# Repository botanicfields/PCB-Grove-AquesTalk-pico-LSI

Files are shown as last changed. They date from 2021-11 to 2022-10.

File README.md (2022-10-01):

# PCB-Grove-AquesTalk-pico-LSI
# AquesTalk pico LSI用Grove(M5)接続基板
AquesTalk pico LSI into the Grove of M5

# 1. 概要
　「AquesTalk pico LSI用Grove(M5)接続基板」は、市販の音声合成専用LSI「AquesTalk pico LSI」（別売）をGroveコネクタでM5シリーズに接続するための基板です。  
　AquesTalk pico LSIの詳細は、データシートを参照ください。
- [Data Sheet: 音声合成 LSI 「AquesTalk pico LSI」ATP3011](https://www.a-quest.com/archive/manual/atp3011_datasheet.pdf)
- [Data Sheet: 音声合成 LSI 「AquesTalk pico LSI」ATP3012](https://www.a-quest.com/archive/manual/atp3012_datasheet.pdf)

### 基板V03 の変更点
　2022年10月から基板V03を提供しています。ピンソケットJ7を追加しました。

### 委託販売
（スイッチサイエンス扱い）[AquesTalk pico LSI用Grove(M5)接続基板](https://www.switch-science.com/catalog/7625/)

### 動作例
- (YouTube）[AquesTalk pico LSI into the Grove of M5](https://youtu.be/mju6NteZsHU)  
M5AtomにI2Cで接続しています。以下のサンプルプログラムを使用しています。  
[GitHub: botanicfields/PCB-Grove-AquesTalk-pico-LSI/tree/main/BF-035_Wire](https://github.com/botanicfields/PCB-Grove-AquesTalk-pico-LSI/tree/main/BF-035_Wire)
- (YouTube）[般若心経 by AquesTalk pico LSI and M5Stack, Glove PCB, I2C](https://youtu.be/BDH4y0ca8p8)  
M5SrackにI2Cで接続しています。基板V03のJ7とM5StackのGPIO35をジャンパワイヤーで接続しています。以下のサンプルプログラムを使用しています。  
[GitHub: botanicfields/PCB-MBUS-AquesTalk-pico-LSI/tree/main/BF-034_han-nya](https://github.com/botanicfields/PCB-MBUS-AquesTalk-pico-LSI/tree/main/BF-034_han-nya)

### 組み立て例
　AquesTalk piso LSI（28ピンDIPタイプ）1個をICソケットに装着します。ATP3011用とATP3012用のソケットがあります。どちらか一方のみを装着してください。  
AquestTalk pico LSIの取り付け: 左 ATP3011, 右 ATP3012  
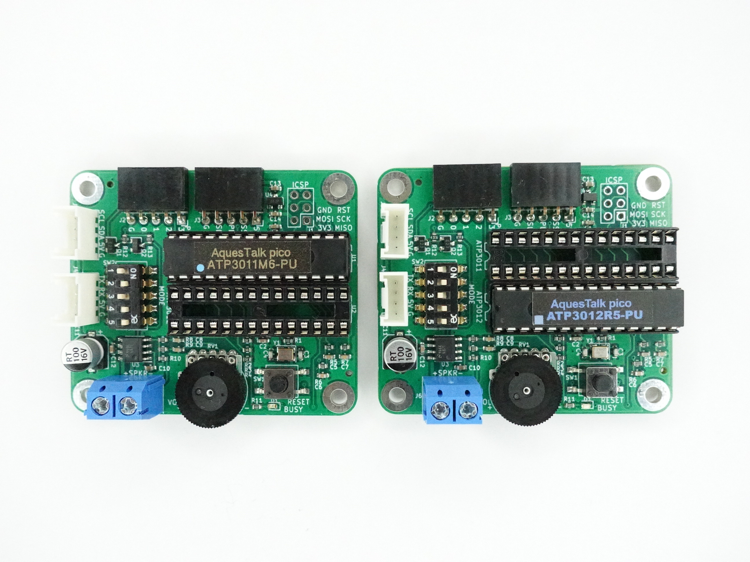
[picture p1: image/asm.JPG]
  

## 1.1 特徴
- AquesTalk pico LSI（28ピンDIPタイプ）1個を搭載できます。
- ATP3011, ATP3012の両方に対応しています。
- パワーアンプ（LM4871）を内蔵し、スピーカーを直接駆動できます。
- M5シリーズのGrove仕様に合わせ、電源+5V、信号3.3Vに対応します。
- AquestTalk pico LSIは3.3Vで動作し、M5シリーズに直結できます。
- DIPスイッチで動作モード・通信モードを設定できます。
- 動作モード・通信モードの変更を反映するリセットボタンがあります。
- I2C接続用、UART接続用のGroveコネクタがあり、接続方法を選べます。
- スタンドアロンモードのためのコネクタがあります。
- SPI接続も可能です（ハンダ付けが必要です）。

DIP: Dual In-line Package  
I2C: Inte-Integrated Circuit  
UART: Universal Asynchronous Receiver Transmitter  
SPI: Serial Peripheral Interface

## 1.2 内容物
- AquesTalk pico LSI用Grove(M5)接続基板（完成品）1枚  
- Groveケーブル20cm 1本（M5Stack純正品）  
- 説明書 1部  

※ AquesTalk pico LSIは付属しません。  
※ スピーカー、スピーカーケーブルは付属しません。  
※ ケースや足などは付属しません。

### 商品写真（基板V03）
写真: 内容物、基板裏面  
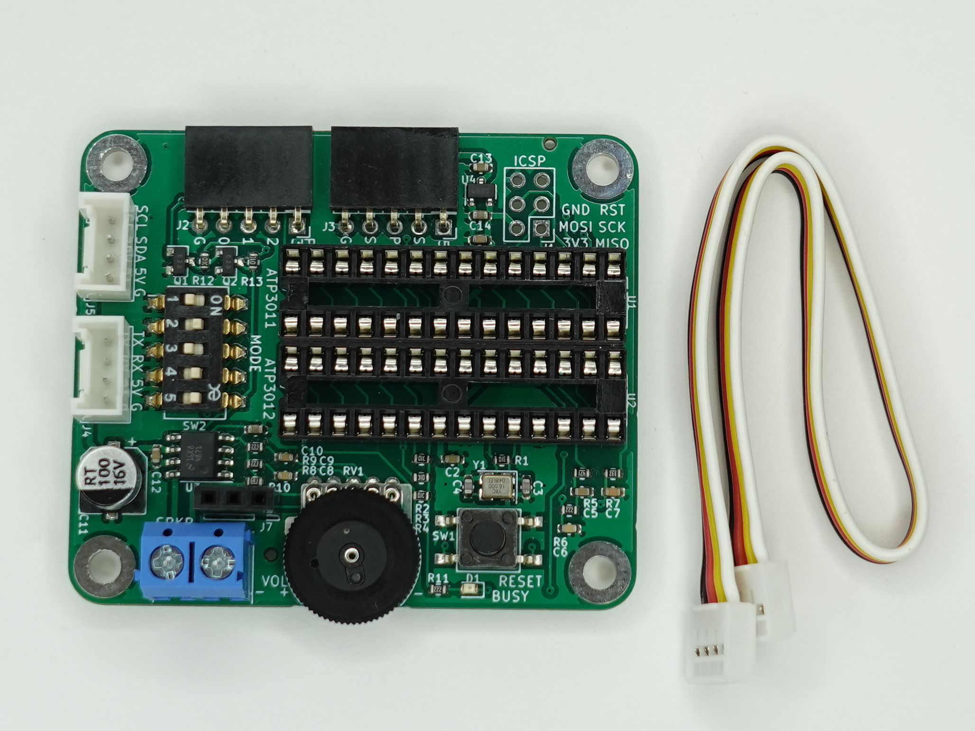
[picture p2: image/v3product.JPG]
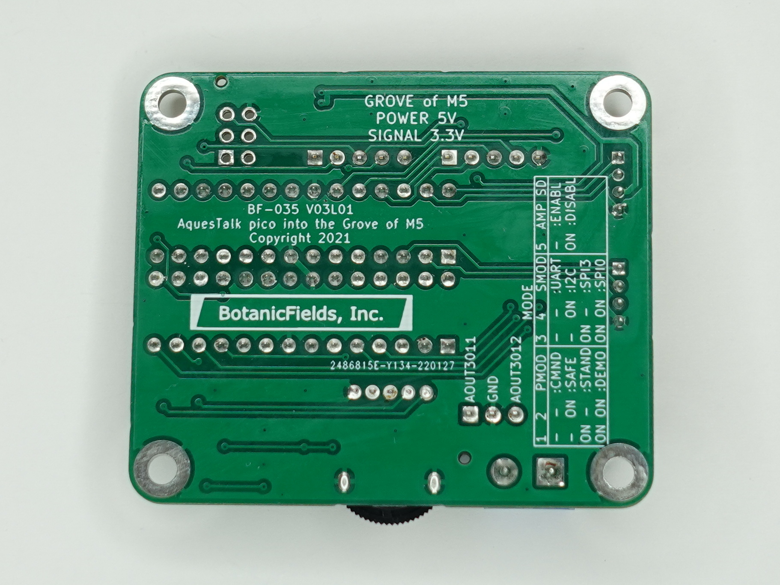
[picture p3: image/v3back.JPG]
   

## 1.3 別途必要なもの
- AquesTalk pico LSI（秋月電子通商扱い）  
[音声合成ＬＳＩ　ＡＴＰ３０１１Ｆ１－ＰＵ（ゆっくりな女性の音声）
ATP3011F1-PU](https://akizukidenshi.com/catalog/g/gI-06220/)  
[音声合成ＬＳＩ　ＡＴＰ３０１１Ｆ４－ＰＵ（かわいい女性の音声）
ATP3011F4-PU](https://akizukidenshi.com/catalog/g/gI-05665/)  
[音声合成ＬＳＩ　ＡＴＰ３０１１Ｍ６－ＰＵ（男性の音声）
ATP3011M6-PU](https://akizukidenshi.com/catalog/g/gI-06225/)  
[音声合成ＬＳＩ　ＡＴＰ３０１２Ｆ６－ＰＵ（女性の音声明瞭版）
ATP3012F6-PU](https://akizukidenshi.com/catalog/g/gI-09973/)  
[音声合成ＬＳＩ　ＡＴＰ３０１２Ｒ５－ＰＵ（小型ロボットの音声）
ATP3012R5-PU](https://akizukidenshi.com/catalog/g/gI-11517/)  
- スピーカー、スピーカーケーブル  
4～8Ω程度、1W以上が望ましいです
- 工具  
ドライバ（ターミナルブロックの締め付けに必要です）など
- M5Stack, M5Atom  
サンプルプログラムは、M5Stack Core Basic, M5Atomで動作を確認しています
- Arduino-IDEが動作する環境  
サンプルプログラムは、Arduino IDE用です
- その他  
SLEEP信号などを接続する場合には、ジャンパワイヤー等が必要です。SPI接続の場合には、ピンヘッダおよびハンダ付けが必要です

# 2. 接続

## 2.1 I2C接続
　SCL, SDAの表記のあるGroveコネクタJ5に接続します。基板上にプルアップ抵抗はありません。M5シリーズ側でのプルアップを使用します。

### (1)M5AtomのGroveコネクタに接続  
　I2Cとして、SCL=GPIO32, SDA=GPIO26を指定します。サンプルプログラムではWire1を選択します。

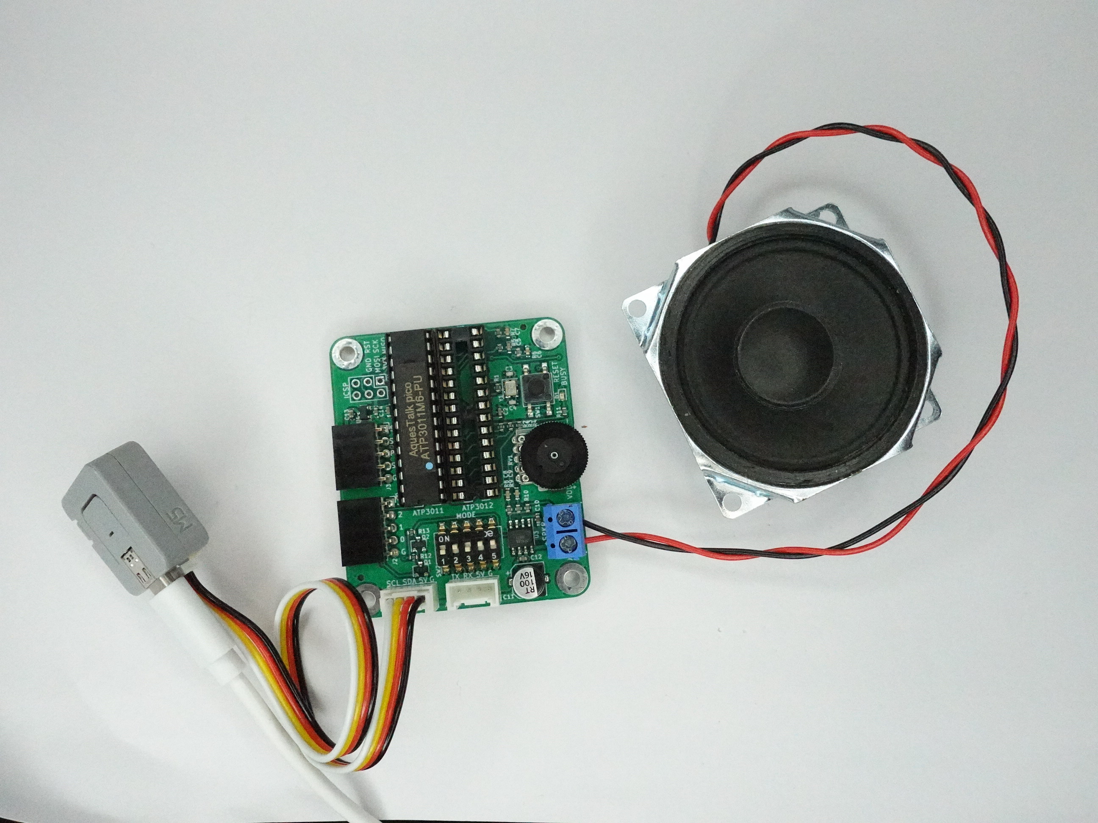
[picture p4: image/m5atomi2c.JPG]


### (2)「M5Atom用GROVEコネクタ基板※（別売）」経由で接続  
　I2Cとして、デフォルトのWire（SCL=GPIO21, SDA=GPIO25）を使用できます。  
※（スイッチサイエンス扱い）[M5Atom用GROVEコネクタ基板](https://www.switch-science.com/catalog/7309/)

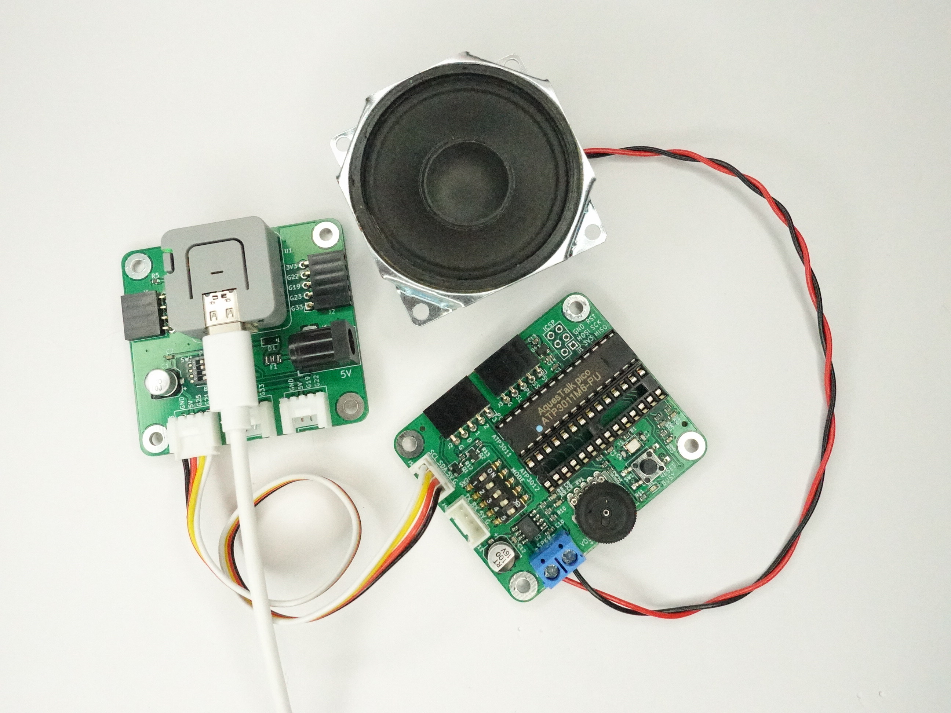
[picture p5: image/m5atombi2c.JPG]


### (3)M5StackのGroveコネクタに接続  
　I2Cとして、デフォルトのWire（SCL=GPIO22, SDA=GPIO21）を使用できます。

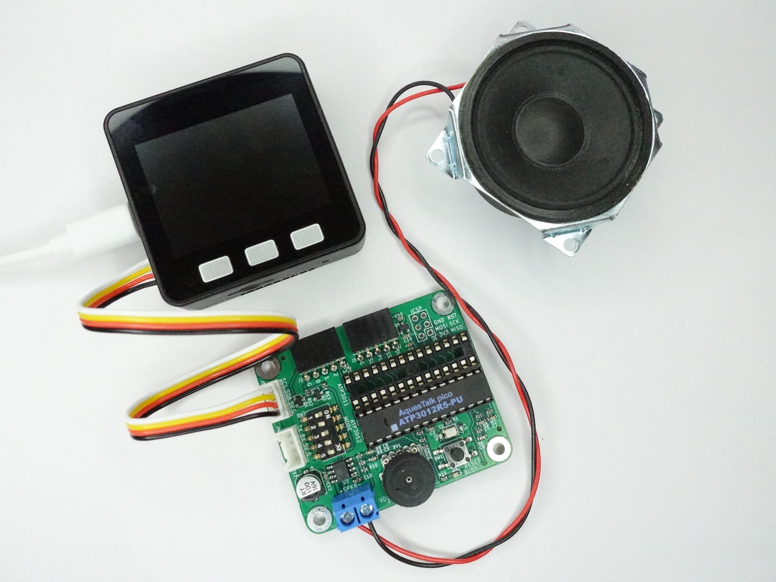
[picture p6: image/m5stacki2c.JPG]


## 2.2 UART接続
　TX, RXの表記のあるGroveコネクタJ4に接続します。基板上のTXがM5シリーズのRXに、基板上のRXがM5シリーズのTXに接続されます。

### (1)M5AtomのGroveコネクタに接続  
　M5Atom側は、RX=GPIO32, TX=GPIO26を指定します。

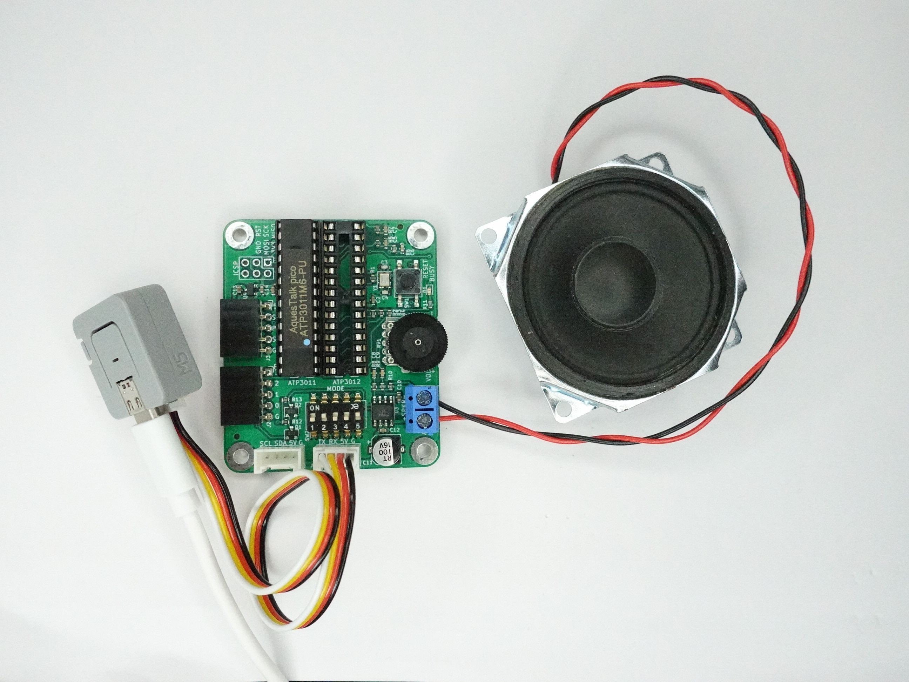
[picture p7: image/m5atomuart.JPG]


### (2)M5StackのGPIOに接続  
　接続には、「GROVE - 4ピン - ジャンパオスケーブル※（別売）」相当のケーブルが必要です。M5Stack側は、RX=GPIO16, TX=GPIO17, +5V, GND を接続します。  
※（スイッチサイエンス扱い）[GROVE - 4ピン - ジャンパオスケーブル](https://www.switch-science.com/catalog/6245/)

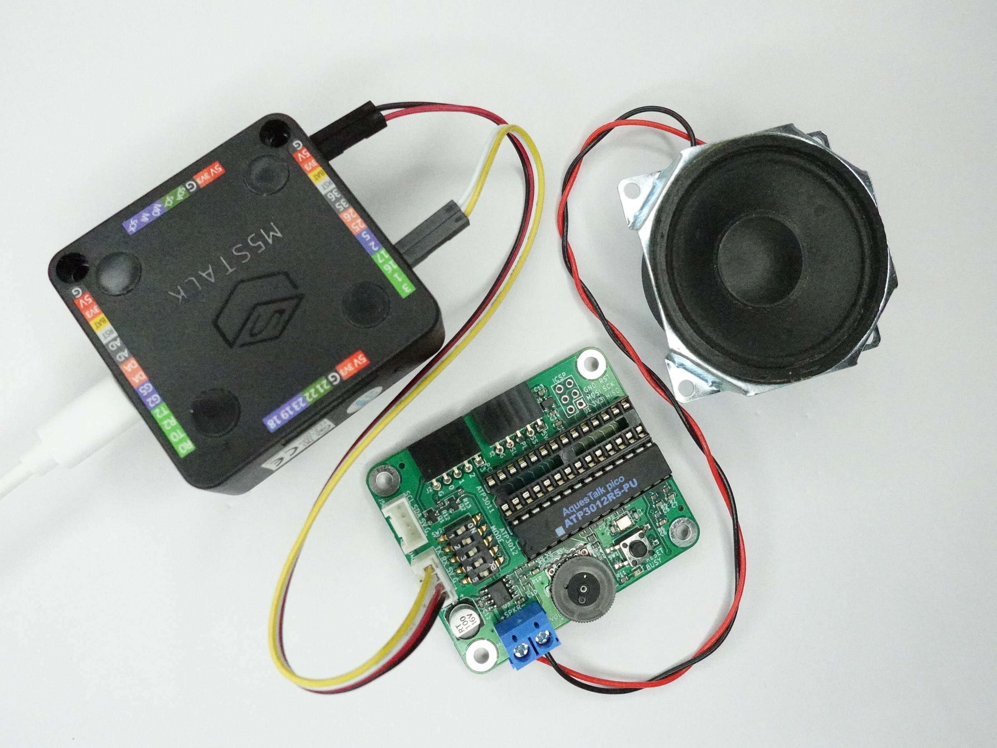
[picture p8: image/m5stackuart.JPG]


## 2.3 SPI接続
　SS, +5V, GNDは、ピンソケットJ3に接続します。SCK, MOSI, MISOは、J1(ICSP)に接続します。ICSPのピンヘッダは実装していません。ピンヘッダを別途手配いただき、基板へハンダ付けしてください。接続にはジャンパワイヤー等が必要です。
- SPI: Serial Periphral Interface
- SCK: Serial ClocK
- MOSI: Master Out Slave In
- MISO: Master In Slave Out
- SS: Slave Select
- GND: Ground
- ICSP: In Circuit Serial Programming

### M5StackのGPIOに接続
　接続にはジャンパワイヤー等が必要です。SCK=GPIO18, MISO=GPIO19, MOSI=GPIO23, SS=GPIO5, +5V, GND を接続します。

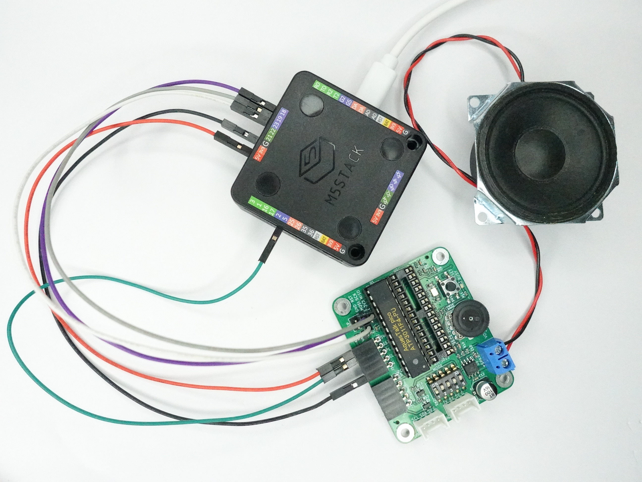
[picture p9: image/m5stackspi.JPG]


## 2.4 スタンドアロン
　J2に「ダイオードマトリクススイッチ16基板※」を接続し、ボタン操作で15種類の音声を再生できます。以下の写真でM5Stackは、電源として使用しています。  
※（スイッチサイエンス扱い）[ダイオードマトリクススイッチ16基板](https://www.switch-science.com/catalog/7626/)

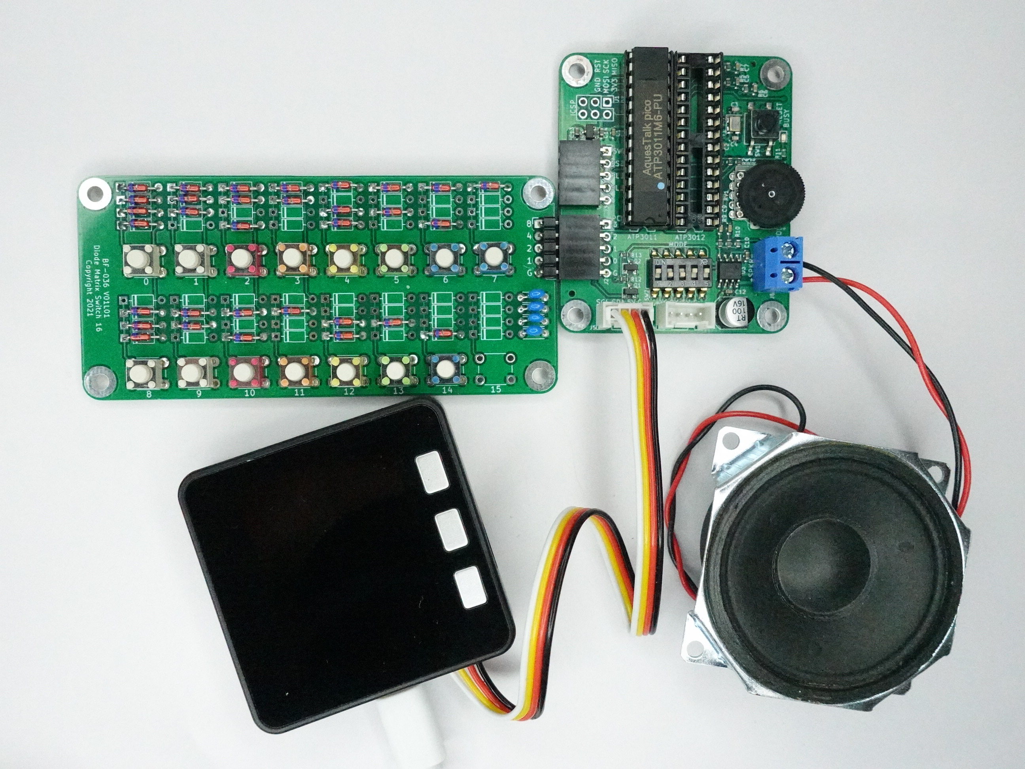
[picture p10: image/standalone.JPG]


## 2.5 その他共通
### J3 SLEEP信号
　AquesTalk pico LSIのSLEEPピンをGPIOに接続できます。SLEEP=LowでAquesTalk pico LSIがスリープ状態になります。ATP3011のUART接続において9600bpsより速い速度が必要な場合、「セーフモード」ではなく「コマンド入力モード」が必要であり、速度設定のためにSLEEPの接続が必要です。

### J3 PLAY信号
　AquesTalk pico LSIのPLAYピンをGPIOに接続できます。AquesTalk pico LSIが音声再生中の間、PLAY=Lowとなります。

### J6 スピーカー
　スピーカーを接続します。2本のいずれもGNDではありません。

### J7 音声信号（基板V03）
　音量調節ボリュームに入る時点のアナログ音声をジャンパワイヤー等に取り出すことができます。ATP3011、ATP3012でピンが異なります。  
ATP3011の例  
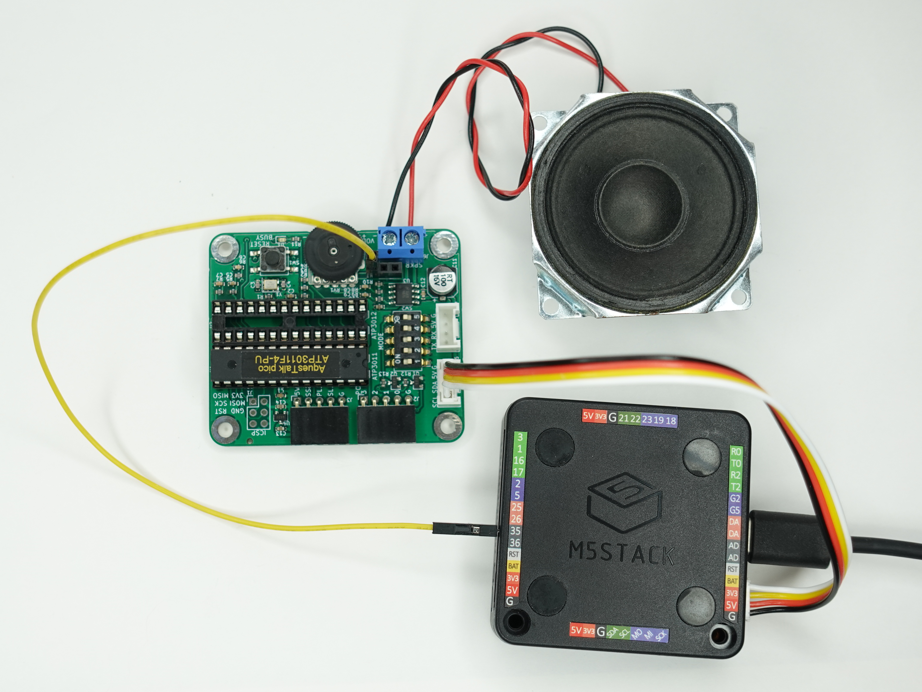
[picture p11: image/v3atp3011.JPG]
  
ATP3012の例  
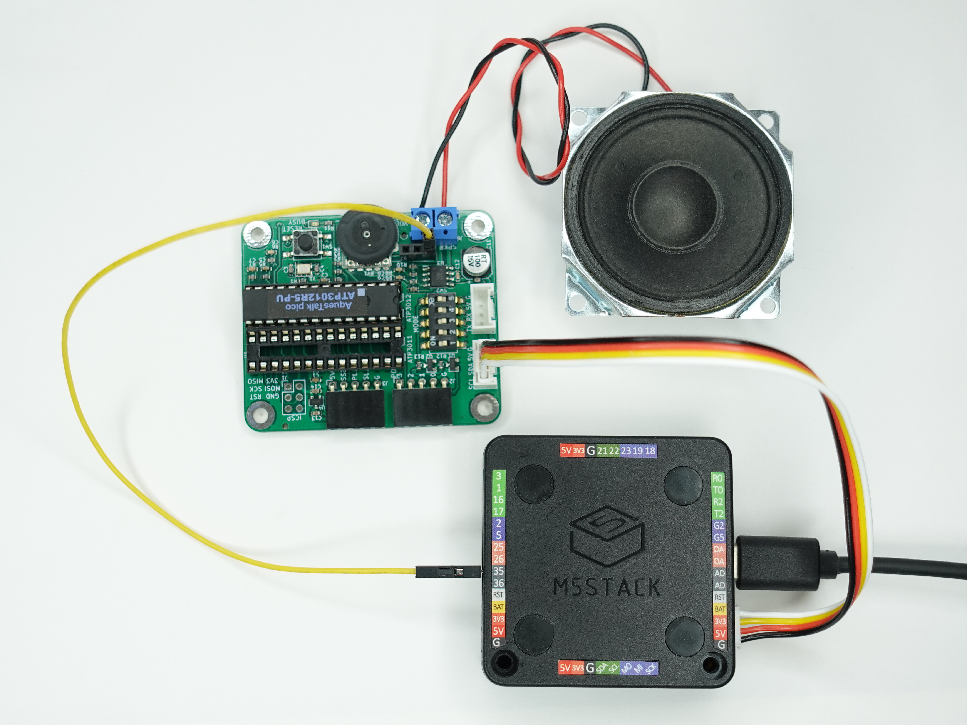
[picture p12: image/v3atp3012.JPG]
  

# 3. 設定（DIPスイッチ）
　動作モードおよび使用するインタフェース（通信モード）に合わせて、基板上のDIPスイッチを設定します。おすすめはI2C接続です。DIPスイッチの設定はリセット時に反映されます。**DIPスイッチの設定を変更後、基板上のリセットボタンを押す必要があります**。出荷時の設定は、セーフモード・I2C接続・パワーアンプが常に動作状態（OFF,ON,OFF,ON,ON）です。

| 1 | 2 | 3 | 4 | 5 |動作モード|通信モード|備考|
|:-:|:-:|:-:|:-:|:-:|:-:|:-:|:- |
|OFF|OFF|OFF|ON | - | コマンド入力モード |I2C |I2CアドレスはEEPROMに設定した値（初期値0x2E）|
|OFF|ON |OFF|ON | - | セーフモード |I2C |I2Cアドレスは強制的に0x2E|
|OFF|OFF|OFF|OFF| - | コマンド入力モード |UART|設定されたスピードで動作 (*1) |
|OFF|ON |OFF|OFF| - | セーフモード |UART|強制的に9600bpsで動作|
|OFF| - |ON |OFF| - | - | SPI mode 3 | - |
|OFF| - |ON |ON | - | - | SPI mode 0 |サンプルプログラムはSPI mode 0で動作|
|ON |OFF| - | - | - | スタンドアロンモード | - |PC0-3の信号入力によりプリセットメッセージを選択して再生|
|ON |ON | - | - | - | デモモード | - |プリセットメッセージを順番に自動再生|
| - | - | - | - |ON | - | - |パワーアンプが常に動作状態 |
| - | - | - | - |OFF| - | - |音声再生中以外は、パワーアンプをシャットダウンする(*2)|

※ 1, 2, 3, 4, 5は、DIPスイッチの番号です。DIPスイッチはONでGND接続のため、ON=0, OFF=1です。  
(*1) ATP3011の場合、SLEEP解除後の'?'送信で自動設定します。ATP3012の場合EEPROMに設定します。  
(*2) 音声再生の前後にノイズが発生します。

# 4. サンプルプログラム
　AquesTalk pico LSIをM5StackまたはM5Atomに接続し、I2C(Wire), UART(Serial), SPIで動作させるプログラムです。デモの内容は同じです。Arduino-IDE環境で使用します。基板の接続や設定を予め使用するインタフェースに合わせておく必要があります。

### BF-035_Wireフォルダ
　AqeusTalk pico LSIをI2Cで動作させるサンプルプログラムです。#defineでM5Stack, M5Atomのいずれかを選択します。

### BF-035_Serialフォルダ
　AqeusTalk pico LSIをUARTで動作させるサンプルプログラムです。#defineでM5Stack, M5Atomのいずれかを選択します。

### BF-035_Spiフォルダ
　AqeusTalk pico LSIを SPIで動作させるサンプルプログラムです。M5Stack専用です。

## 4.1 ボタン操作 .. loop()
　ボタンを押すと、ソースコードのpreset_msgを発声します。初期値はpreset_msg[0]です。

| M5 | ボタン | 停止中 | 発声中 |
|:-:|:-:|:-:|:-:|
|M5Stack| A | 1つ前のpreset_msgを発声 | 発声を中断して1つ前のpreset_msgを発声 |
|M5Stack| B | 現在のpreset_msgを発声 | 発声を中断して停止 |
|M5Stack| C | 1つ後のpreset_msgから連続して発声 | 発声を中断して1つ後のpreset_msgから連続して発生 |
|M5Atom | Btn | 現在のpreset_msgから連続して発声 | 発声を中断して停止 |

## 4.2 setup()
- SLEEPピンをHighにする（デフォルト: 実行しない）  
　AquesTalk pico LSIのSLEEPピンとが接続したGPIO5をHIGHにしてSLEEPでない状態にします。

- UARTスピードを設定（ATP3011が対象。UARTのみ。デフォルト: 実行しない）  
　AquesTalk pico LSI (ATP3011) のUARTスピードを設定します。GPIO5がAquesTalk pico LSIのSLEEPピンと接続している必要があります。

- UARTスピードを書き換え（ATP3012が対象。UARTのみ。デフォルト: 実行しない）  
　AquesTalk pico LSI (ATP3012) のUARTスピードを書き換えます。

- I2Cアドレスを書き換え（I2Cのみ。デフォルト: 実行しない）  
　AquesTalk pico LSIのI2Cアドレスを書き換えます。

- プリセットメッセージを書き込む（デフォルト: 実行しない）  
　AquesTalk pico LSIにプリセットメッセージとして、ソースコード内のpreset_msgデータを書き込みます。時間がかかります。

- EEPROMデータをダンプ（デフォルト: 実行しない）  
　AquesTalk pico LSIのEEPROMデータをシリアルモニタに表示します。時間がかかります。

- AquesTalk pico LSIのバージョンをシリアルモニタに表示

- チャイムJを発声

- チャイムKを発声

# 5. ライブラリ
　AquesTalk pico LSIを使用するためのライブラリです。

## 5.1 BF_AquesTalkPico.h
　I2C, UART, SPI共通の基本クラスです。接続するインタフェースに依ってI2C(Wire), UART(Serial), SPIのいずれかの派生クラスを使用する必要があります。

### (1) virtual int Send(const char* msg) = 0
　AquesTalk pico LSIに文字列msgを送信します。送信の様子をシリアルモニタに出力します。純粋仮想関数として定義し、使用するインタフェースに合わせて派生クラスで実装します。

### (2) virtual size_t Recv(char* res, size_t res_size) = 0
　AquesTalk pico LSIから文字列を受信します。受信完了は、'>'または'*'で判断します。純粋仮想関数として定義し、使用するインタフェースに合わせて派生クラスで実装します。

### (3) virtual bool Busy() = 0
　発声中などAquesTalk pico LSIが処理中の場合trueを応答します。falseの場合発声が終了したと判断できます。純粋仮想関数として定義し、使用するインタフェースに合わせて派生クラスで実装します。I2C, SPIではおのずとポーリングができますが、UARTではSend()による明示的なポーリングが必要です。

### (4) int ShowRes(int res_length_to_show = 1)
　AquesTalk pico LSIからの応答をシリアルモニタに出力します。res_length_to_showに2を渡すと、応答が1文字以下の場合にシリアルモニタへの出力を抑止できます。I2C、SPIのポーリングによる応答が正常（'>', 1文字）の場合のシリアルモニタへの出力を省略できます。

### (5) int DumpEeprom()
　AquesTalk pico LSIのEEPROM (アドレス0x000-0x3FF) の値をシリアルモニタに出力します。

### (6) int WriteEeprom(int address, int data)
　AquesTalk pico LSIのEEPROMにデータを書き込みます。

### (7) int WritePresetMsg(const char* msg[], int num_of_msg)
　AquesTalk pico LSIのEEPROMにプリセットメッセージを書き込みます。書き込みの様子をシリアルモニタに出力します。

### (8)  int WriteSpeed(int speed)
　発話速度をEEPROMに設定します。50～300を設定できます。デフォルトは100です。

### (9)  int WritePause(int pause)
　文末ポーズの長さをEEPROMに設定します。256～65535を設定できます。65535を設定すると自動になります。デフォルトは65535です。

### (10) int WriteSerialSpeed(int serial_speed)
　AquesTalk pico LSI (ATP3012) のシリアル通信速度を書き換えます。デフォルトは9600です。

### (11) int WriteI2cAddress(int i2c_address)
　AquesTalk pico LSIのI2Cアドレスを書き換えます。デフォルトは0x2Eです。

## 5.2 BF_AquesTalkPicoWire.h
　AquesTalk pico LSIとI2Cでインタフェースする派生クラスです。

### int Begin(TwoWire &wire, int i2c_address = 0x2e);
　AquesTalk pico LSIを接続するI2CとI2Cアドレスを指定します。

## 5.3 BF_AquesTalkPicoSerial.h
　AquesTalk pico LSIとUARTでインタフェースする派生クラスです。

### int Begin(Stream &stream);
　AquesTalk pico LSIを接続するUARTを指定します。

## 5.4 BF_AquesTalkPicoSpi.h
　AquesTalk pico LSIとSPIでインタフェースする派生クラスです。

### int Begin(SPIClass &spi, int ss);
　AquesTalk pico LSIを接続するSPIとSSとして使用するGPIOを指定します。

# 6. 参考
Qiita: [AquesTalk pico LSI を M5Stack の I2C, UART, SPI で動かす](https://qiita.com/BotanicFields/items/fff644f408c291e5a5f0)

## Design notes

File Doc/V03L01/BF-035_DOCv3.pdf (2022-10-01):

BF-035 V03L01

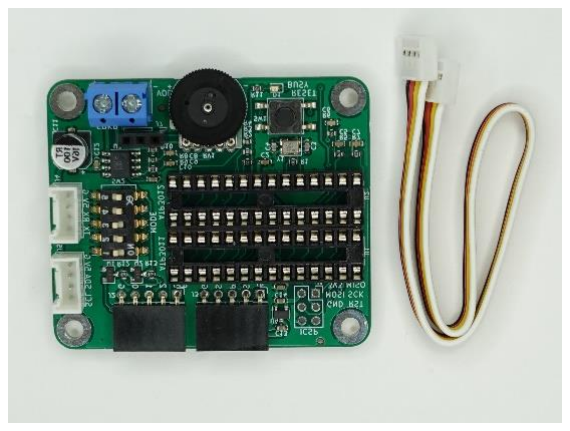
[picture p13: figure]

1 | Copyright 2022 BotanicFields, Inc.

## AquesTalk pico LSI 用 Grove(M5)接続基板

市販の音声合成専用 LSI「AquesTalk pico LSI」（別売）を Grove コネ クタで M5 シリーズに接続するための基板です。
詳細は、以下を参照ください。
GitHub「PCB-Grove-AquesTalk-pico-LSI」 https://github.com/botanicfields/PCB-Grove-AquesTalk-pico-LSI Qiita「AquesTalk pico LSI を M5Stack の I2C, UART, SPI で動かす」 https://qiita.com/BotanicFields/items/fff644f408c291e5a5f0

AquesTalk pico LSI の詳細は、データシートを参照ください。 ATP3011: https://www.a-quest.com/archive/manual/atp3011_datasheet.pdf ATP3012: https://www.a-quest.com/archive/manual/atp3012_datasheet.pdf

1. 特徴
① AquesTalk pico LSI（28 ピン DIP タイプ）1 個を搭載できます。
② ATP3011, ATP3012 の両方に対応しています。
③ パワーアンプ（LM4871）を内蔵し、スピーカーを直接駆動できます。 ④ M5 シリーズの Grove 仕様に合わせ、電源+5V、信号 3.3V に対応します。 ⑤ AquesTalk pico LSI は 3.3V で動作し、M5 シリーズに直結できます。
⑥ DIP スイッチで動作モード・通信モードを設定できます。
⑦ 動作モード・通信モードの変更を反映するリセットボタンがあります。 ⑧ I2C 接続用、UART 接続用の Grove コネクタがあり、接続方法を選べます。 ⑨ スタンドアロンモードのためのコネクタがあります。
⑩ SPI 接続も可能です（ハンダ付けが必要です）。
2. 商品内容
① AquesTalk pico LSI 用 Grove(M5)接続基板（完成品）1 枚 ② Grove ケーブル 20cm 1 本（M5Stack 純正品）
③ 説明書 1 部
3. 別途必要なもの
① AquesTalk pico LSI（秋月電子通商扱い）
音声合成ＬＳＩ ＡＴＰ３０１１Ｆ１－ＰＵ（ゆっくりな女性の音声） 音声合成ＬＳＩ ＡＴＰ３０１１Ｆ４－ＰＵ（かわいい女性の音声） 音声合成ＬＳＩ ＡＴＰ３０１１Ｍ６－ＰＵ（男性の音声） 音声合成ＬＳＩ ＡＴＰ３０１２Ｆ６－ＰＵ（女性の音声明瞭版） 音声合成ＬＳＩ ＡＴＰ３０１２Ｒ５－ＰＵ（小型ロボットの音声）
② スピーカー: 4～8Ω 程度、1W 以上が望ましいです。
③ スピーカーケーブル: スピーカーを基板上のターミナルブロックに接続します。 ④ 工具類: ドライバ（ターミナルブロックの締め付けに必要）など

⑤ M5Stack, M5Atom: サンプルプログラムは、M5Stack Core Basic, M5Atom で動作確認しています。 ⑥ Arduino-IDE が動作する環境: サンプルプログラムを使用する際に必要です。

4. 組み立て・接続
① AquesTalk pico LSI の取り付け
AquesTalk piso LSI（28 ピン DIP タイプ）1 個を IC ソケットに装着します。ATP3011 用と ATP3012 用の ソケットがあります。どちらか一方のみを装着してく
ださい。
② スピーカーの接続

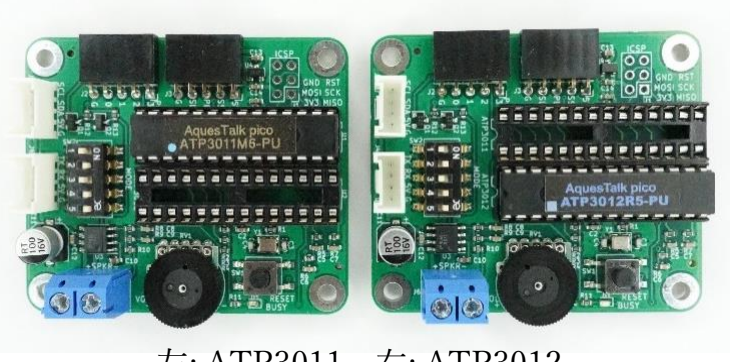
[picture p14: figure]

ターミナルブロックとスピーカーをケーブルで接続します。ケーブルは別途ご用意ください。GND には接続しないでください。
③ インタフェースの接続
I2C 接続の場合、SCL, SDA の表記のある Grove コネクタ J5 に接続します。基板上にプルアップ抵 抗はありません。M5 シリーズ側でのプルアップを使用します。
UART 接続の場合、TX, RX の表記のある Grove コネクタ J4 に接続します。基板上の TX を M5 シリ ーズの RX に、基板上の RX を M5 シリーズの TX に接続します。
5. DIP スイッチの設定
動作モードおよび使用するインタフェース（通信モード）に合わせて、基板上の DIP スイッチを設定しま す。おすすめは I2C 接続です。DIP スイッチの設定はリセット時に反映されます。DIP スイッチの設定を変 更後、基板上のリセットボタンを押す必要があります。出荷時の設定は、セーフモード・I2C 接続・パワー アンプが常に動作状態（OFF,ON,OFF,ON,ON）です。

(*1) ATP3011 の場合 SLEEP 解除後の'?'送信で自動設定。ATP3012 の場合 EEPROM に設定 (*2) 音声再生の前後にノイズが発生します。

DIP スイッチ

1 | 2 | 3 | 4 | 5 | 動作モード | 通信モード | 備考
OFF | OFF | OFF | ON | - | コマンド入力モード | I2C | I2C アドレスは EEPROM に設定した値 （初期値 0x2E）
OFF | ON | OFF | ON | - | セーフモード | I2C | I2C アドレスは強制的に 0x2E
OFF | OFF | OFF | OFF | - | コマンド入力モード | UART | 設定されたスピードで動作 (*1)
OFF | ON | OFF | OFF | - | セーフモード | UART | 強制的に 9600bps で動作
OFF | - | ON | OFF | - | - | SPI mode 3 | -
OFF | - | ON | ON | - | - | SPI mode 0 | サンプルプログラムは SPI mode 0 で動作
ON | OFF | - | - | - | スタンドアロンモード | - | PC0-3 の信号入力により プリセットメッセージを選択して再生
ON | ON | - | - | - | デモモード | - | プリセットメッセージを順番に自動再生
- | - | - | - | ON | - | - | パワーアンプが常に動作状態
- | - | - | - | OFF | - | - | 音声再生中以外は、 パワーアンプをシャットダウンする(*2)

左: ATP3011 右: ATP3012

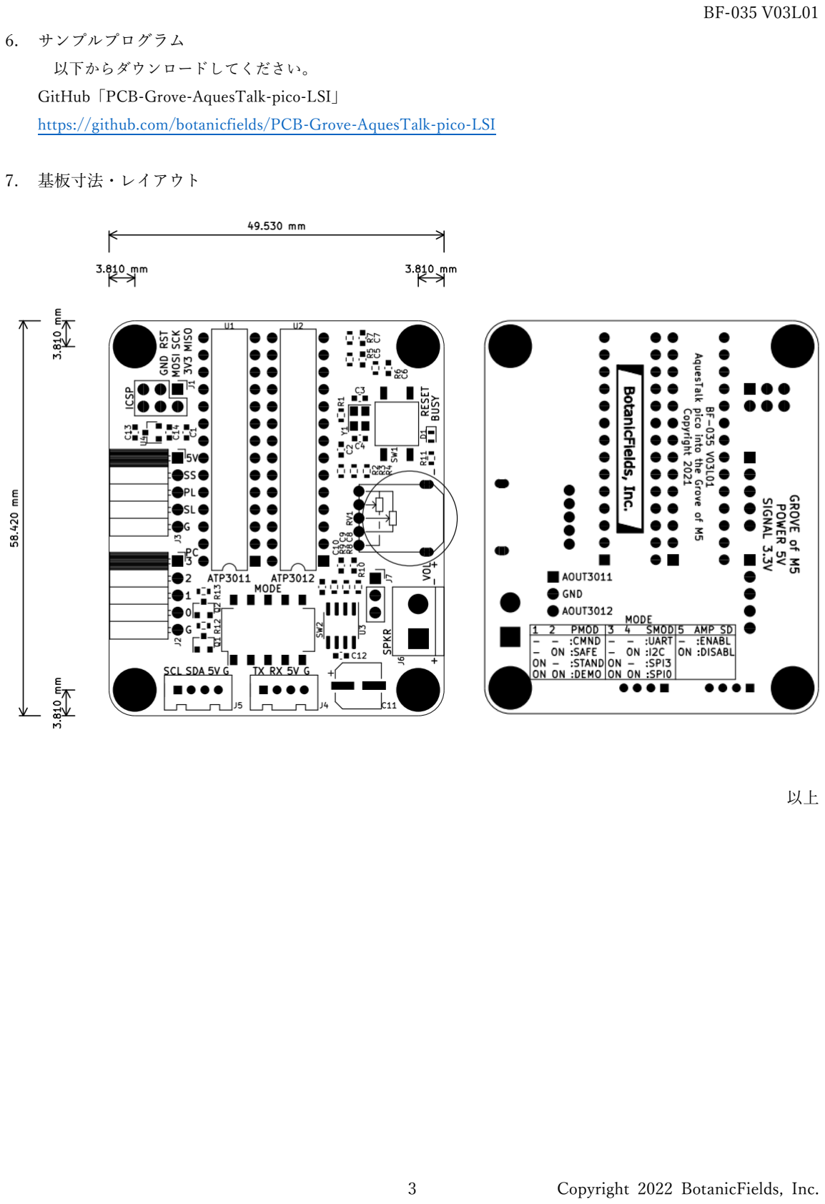
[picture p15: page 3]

6. サンプルプログラム

以下からダウンロードしてください。

GitHub「PCB-Grove-AquesTalk-pico-LSI」

https://github.com/botanicfields/PCB-Grove-AquesTalk-pico-LSI

7. 基板寸法・レイアウト

以上

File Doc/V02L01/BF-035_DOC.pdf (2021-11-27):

BF-035 V02L01

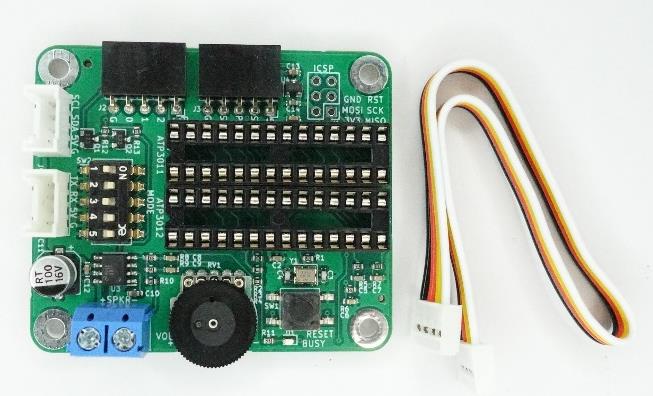
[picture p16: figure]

1 | Copyright 2021 BotanicFields, Inc.

## AquesTalk pico LSI 用 Grove(M5)接続基板

市販の音声合成専用 LSI「AquesTalk pico LSI」（別売）を Grove コネ クタで M5 シリーズに接続するための基板です。
詳細は、以下を参照ください。
GitHub「PCB-Grove-AquesTalk-pico-LSI」 https://github.com/botanicfields/PCB-Grove-AquesTalk-pico-LSI Qiita「AquesTalk pico LSI を M5Stack の I2C, UART, SPI で動かす」 https://qiita.com/BotanicFields/items/fff644f408c291e5a5f0

AquesTalk pico LSI の詳細は、データシートを参照ください。 ATP3011: https://www.a-quest.com/archive/manual/atp3011_datasheet.pdf ATP3012: https://www.a-quest.com/archive/manual/atp3012_datasheet.pdf

1. 特徴
① AquesTalk pico LSI（28 ピン DIP タイプ）1 個を搭載できます。
② ATP3011, ATP3012 の両方に対応しています。
③ パワーアンプ（LM4871）を内蔵し、スピーカーを直接駆動できます。 ④ M5 シリーズの Grove 仕様に合わせ、電源+5V、信号 3.3V に対応します。 ⑤ AquestTalk pico LSI は 3.3V で動作し、M5 シリーズに直結できます。 ⑥ DIP スイッチで動作モード・通信モードを設定できます。
⑦ 動作モード・通信モードの変更を反映するリセットボタンがあります。 ⑧ I2C 接続用、UART 接続用の Grove コネクタがあり、接続方法を選べます。 ⑨ スタンドアロンモードのためのコネクタがあります。
⑩ SPI 接続も可能です。（ハンダ付けが必要です）
2. 商品内容
① AquesTalk pico LSI 用 Grove(M5)接続基板（完成品）1 枚 ② Grove ケーブル 20cm 1 本（M5Stack 純正品）
③ 説明書 1 部
3. 別途必要なもの
① AquesTalk pico LSI（秋月電子通商扱い）
音声合成ＬＳＩ ＡＴＰ３０１１Ｆ１－ＰＵ（ゆっくりな女性の音声） 音声合成ＬＳＩ ＡＴＰ３０１１Ｆ４－ＰＵ（かわいい女性の音声） 音声合成ＬＳＩ ＡＴＰ３０１１Ｍ６－ＰＵ（男性の音声） 音声合成ＬＳＩ ＡＴＰ３０１２Ｆ６－ＰＵ（女性の音声明瞭版） 音声合成ＬＳＩ ＡＴＰ３０１２Ｒ５－ＰＵ（小型ロボットの音声）
② スピーカー: 4～8Ω 程度、1W 以上が望ましいです
③ スピーカーケーブル: スピーカーを基板上のターミナルブロックに接続します。 ④ 工具類: ドライバ（ターミナルブロックの締め付けに必要です）など

⑤ M5Stack, M5Atom: サンプルプログラムは、M5Stack Core Basic, M5Atom で動作確認しています ⑥ Arudino-IDE が動作する環境

4. 組み立て・接続
① AquesTalk pico LSI の取り付け
AquesTalk piso LSI（28 ピン DIP タイプ）1 個を IC ソケットに装着します。ATP3011 用と ATP3012 用の ソケットがあります。どちらか一方のみを装着してく
ださい。
② スピーカーの接続

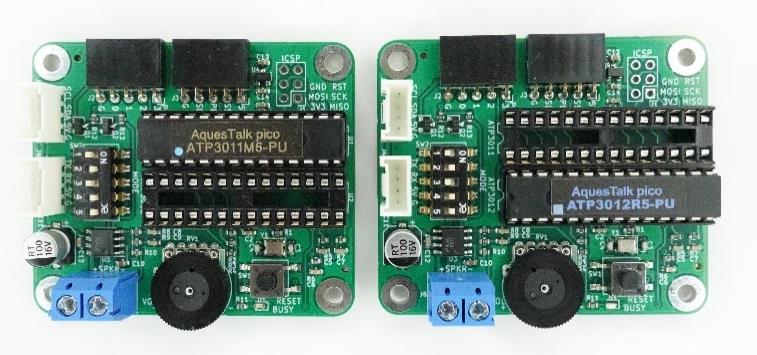
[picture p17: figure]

ターミナルブロックとスピーカーをケーブルで接続します。ケーブルは別途ご用意ください。GND には接続しないでください。
③ インタフェースの接続
I2C 接続の場合、SCL, SDA の表記のある Grove コネクタ J5 に接続します。基板上にプルアップ抵 抗はありません。M5 シリーズ側でのプルアップを使用します。
UART 接続の場合、TX, RX の表記のある Grove コネクタ J4 に接続します。基板上の TX が M5 シリ ーズの RX に、基板上の RX が M5 シリーズの TX に接続されます。
5. DIP スイッチの設定
動作モードおよび使用するインタフェース（通信モード）に合わせて、基板上の DIP スイッチを設定しま す。おすすめは I2C 接続です。DIP スイッチの設定はリセット時に反映されます。DIP スイッチの設定を変 更後、基板上のリセットボタンを押す必要があります。出荷時の設定は、セーフモード・I2C 接続・パワー アンプが常に動作状態（OFF,ON,OFF,ON,ON）です。

(*1) ATP3011 の場合 SLEEP 解除後の'?'送信で自動設定。ATP3012 の場合 EEPROM に設定 (*2) 音声再生の前後にノイズが発生します。

DIP スイッチ

1 | 2 | 3 | 4 | 5 | 動作モード | 通信モード | 備考
OFF | OFF | OFF | ON | - | コマンド入力モード | I2C | I2C アドレスは EEPROM に設定した値 （初期値 0x2E）
OFF | ON | OFF | ON | - | セーフモード | I2C | I2C アドレスは強制的に 0x2E
OFF | OFF | OFF | OFF | - | コマンド入力モード | UART | 設定されたスピードで動作 (*1)
OFF | ON | OFF | OFF | - | セーフモード | UART | 強制的に 9600bps で動作
OFF | - | ON | OFF | - | - | SPI mode 3 | -
OFF | - | ON | ON | - | - | SPI mode 0 | サンプルプログラムは SPI mode 0 で動作
ON | OFF | - | - | - | スタンドアロンモード | - | PC0-3 の信号入力により プリセットメッセージを選択して再生
ON | ON | - | - | - | デモモード | - | プリセットメッセージを順番に自動再生
- | - | - | - | ON | - | - | パワーアンプが常に動作状態
- | - | - | - | OFF | - | - | 音声再生中以外は、 パワーアンプをシャットダウンする(*2)

左: ATP3011 右: ATP3012

6. サンプルプログラム
以下からダウンロードしてください。
GitHub「PCB-Grove-AquesTalk-pico-LSI」 https://github.com/botanicfields/PCB-Grove-AquesTalk-pico-LSI
7. 基板表面

以上

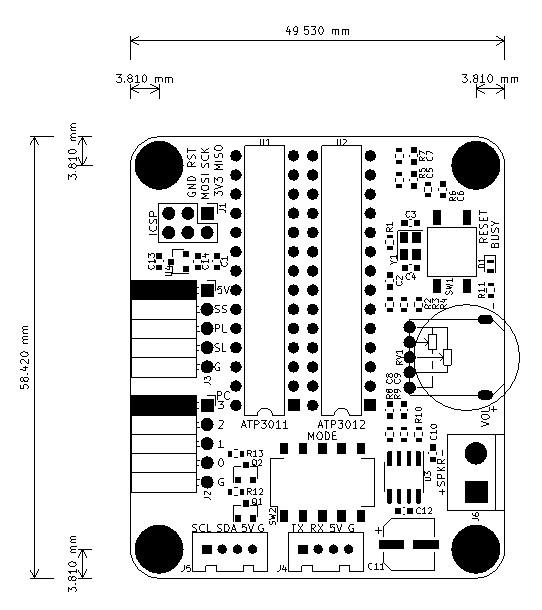
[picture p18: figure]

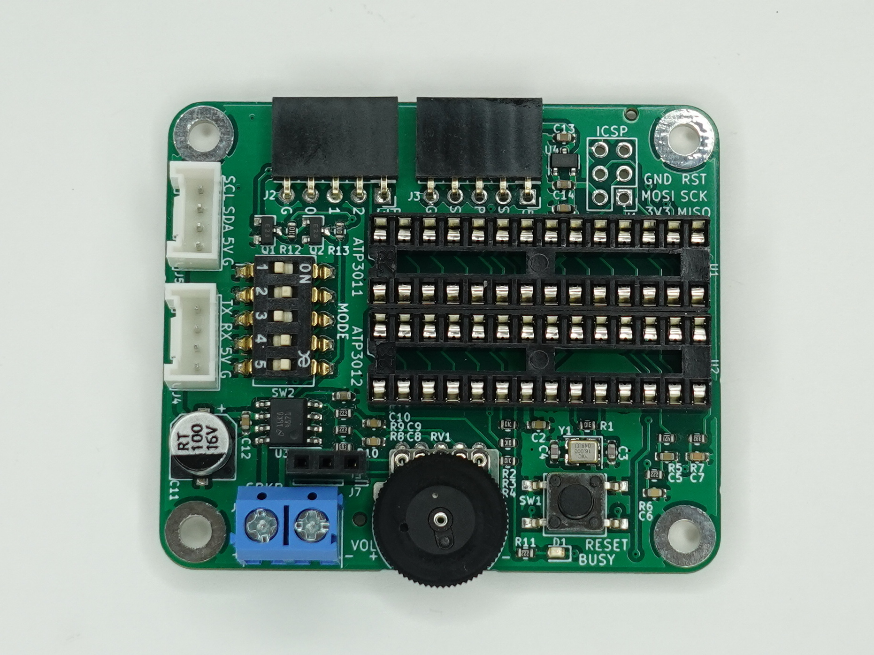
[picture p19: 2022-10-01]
image/v3front.JPG

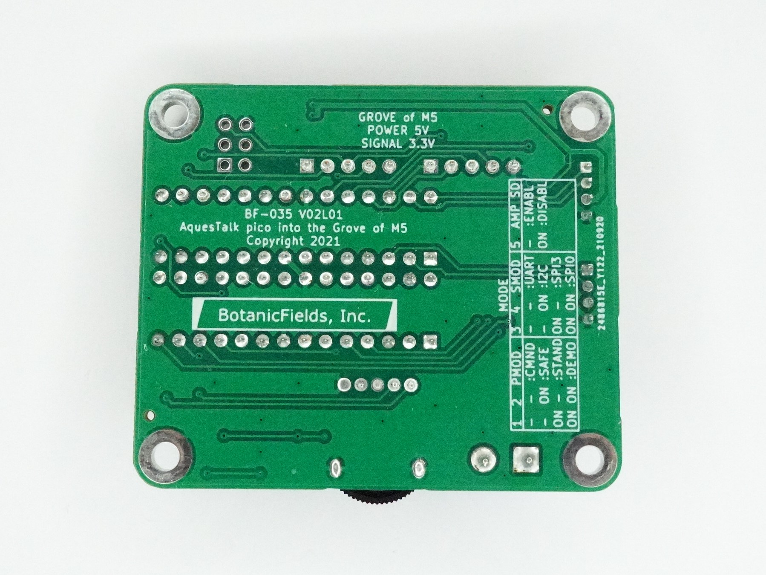
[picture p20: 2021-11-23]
image/product2.JPG

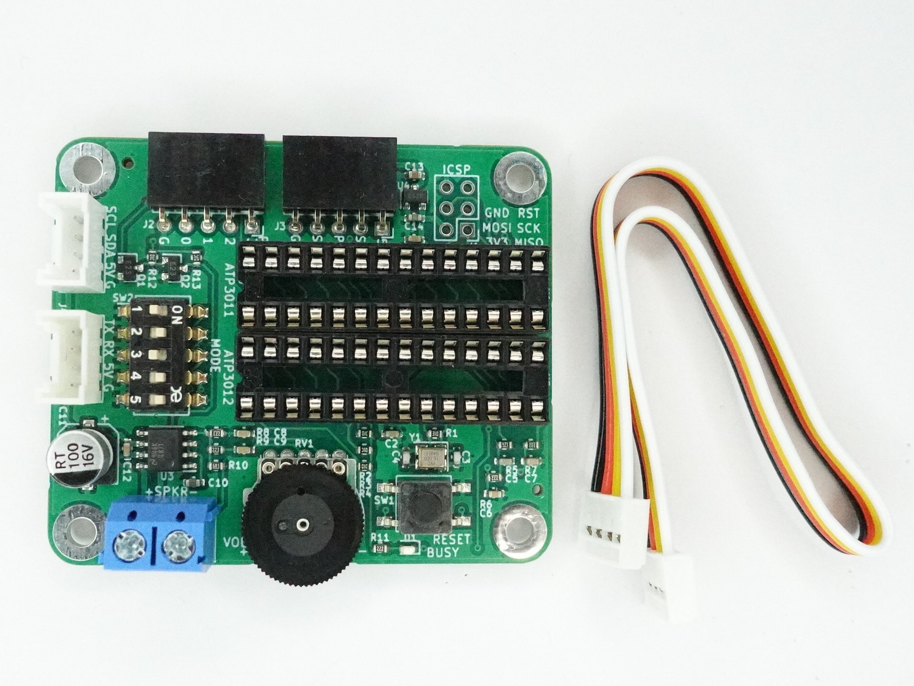
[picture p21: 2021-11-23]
image/product1.JPG

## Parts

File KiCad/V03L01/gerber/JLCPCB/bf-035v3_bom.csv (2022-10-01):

Comment | Designator | Footprint | LCSC
1u | C10,C13,C14 | bf:BF@C_0603_1608Metric | C15849
100u | C11 | bf:BF@CP_Elec_6.3x5.3 | C267461
100n | C1,C2,C5,C12 | bf:BF@C_0603_1608Metric | C14663
10p | C3,C4 | bf:BF@C_0603_1608Metric | C1634
22n | C6 | bf:BF@C_0603_1608Metric | C21122
10n | C7 | bf:BF@C_0603_1608Metric | C57112
33n | C8,C9 | bf:BF@C_0603_1608Metric | C21117
BUSY | D1 | bf:BF@LED_0603_1608Metric | C72038
ICSP | J1 | Connector_PinHeader_2.54mm:PinHeader_2x03_P2.54mm_Vertical
PRESET | J2 | Connector_PinSocket_2.54mm:PinSocket_1x05_P2.54mm_Horizontal
CONTROL | J3 | Connector_PinSocket_2.54mm:PinSocket_1x05_P2.54mm_Horizontal
Grove UART | J4 | OPL_Connector:HW4-2.0
Grove I2C | J5 | OPL_Connector:HW4-2.0
SPKR | J6 | bf:BF@TerminalBlock_2_P5.08mm_d1.3mm
AOUT | J7 | Connector_PinSocket_2.54mm:PinSocket_1x03_P2.54mm_Vertical
DTC143Z | Q1,Q2 | Package_TO_SOT_SMD:SOT-23 | C15236
1M | R1 | bf:BF@R_0603_1608Metric | C22935
68k | R10 | bf:BF@R_0603_1608Metric | C23231
2.2k | R6,R11 | bf:BF@R_0603_1608Metric | C4190
10k | R2,R3,R4,R12,R13 | bf:BF@R_0603_1608Metric | C25804
470 | R5 | bf:BF@R_0603_1608Metric | C23179
3.3k | R7 | bf:BF@R_0603_1608Metric | C22978
22k | R8,R9 | bf:BF@R_0603_1608Metric | C31850
10kA | RV1 | bf:BF@RK10J
SW_Push | SW1 | bf:BF@K2-6639SP | C879344
MODE | SW2 | Button_Switch_SMD:SW_DIP_SPSTx05_Slide_Omron_A6S-510x_W8.9mm_P2.54mm | C54951
ATP3011 | U1 | Package_DIP:DIP-28_W7.62mm
ATP3012 | U2 | Package_DIP:DIP-28_W7.62mm
LM4871 | U3 | Package_SO:SOIC-8_3.9x4.9mm_P1.27mm | C7554
XC6206P332MR | U4 | Package_TO_SOT_SMD:SOT-23 | C5446
16MHz | Y1 | Crystal:Crystal_SMD_3225-4Pin_3.2x2.5mm | C13738

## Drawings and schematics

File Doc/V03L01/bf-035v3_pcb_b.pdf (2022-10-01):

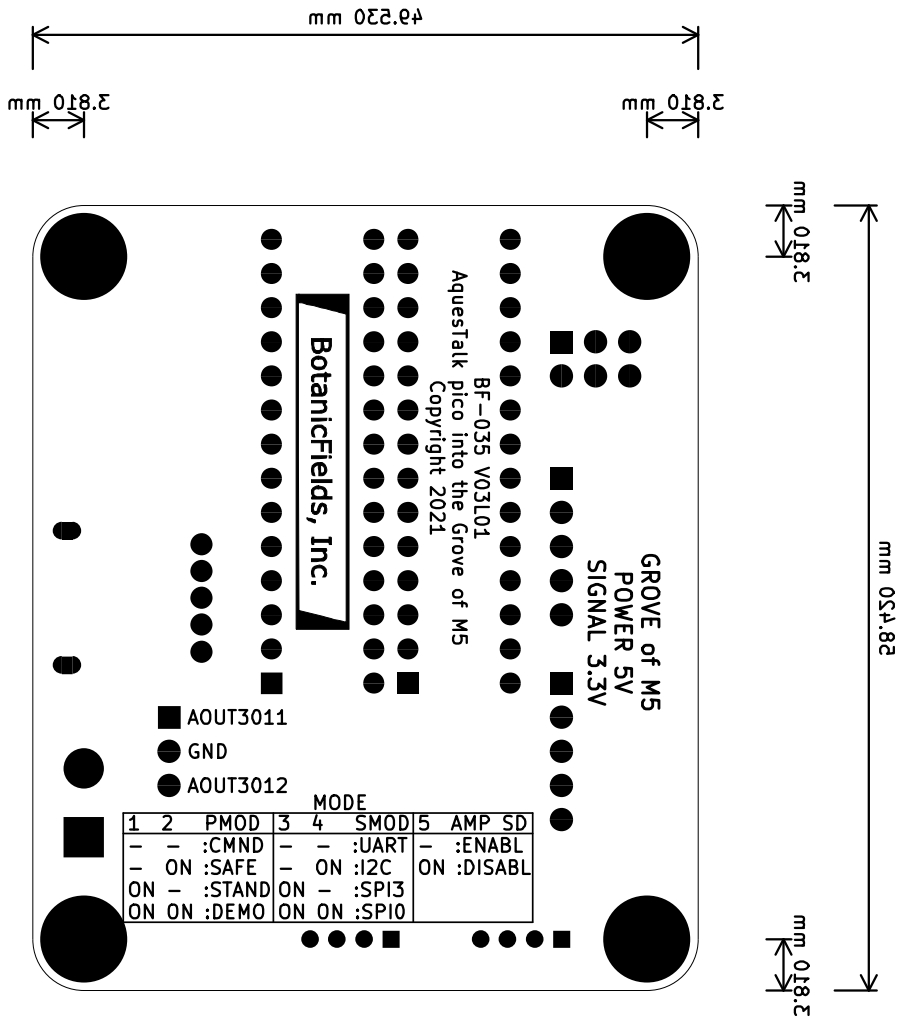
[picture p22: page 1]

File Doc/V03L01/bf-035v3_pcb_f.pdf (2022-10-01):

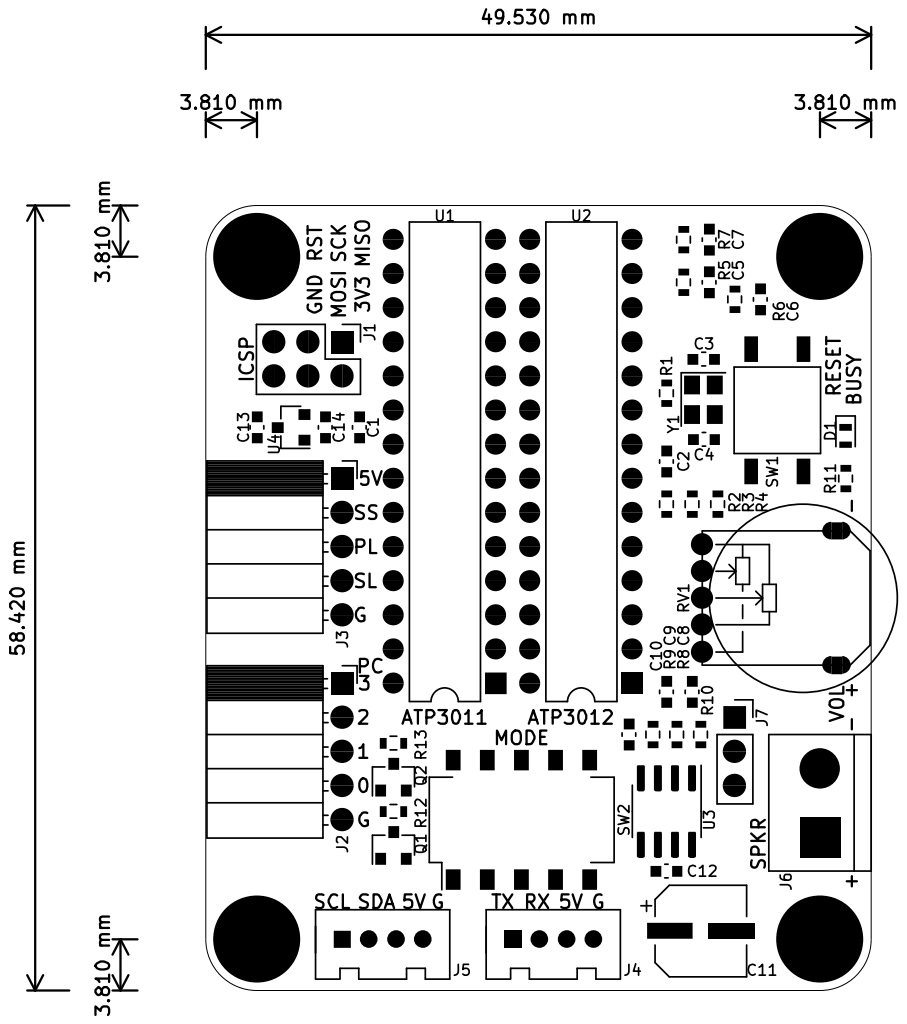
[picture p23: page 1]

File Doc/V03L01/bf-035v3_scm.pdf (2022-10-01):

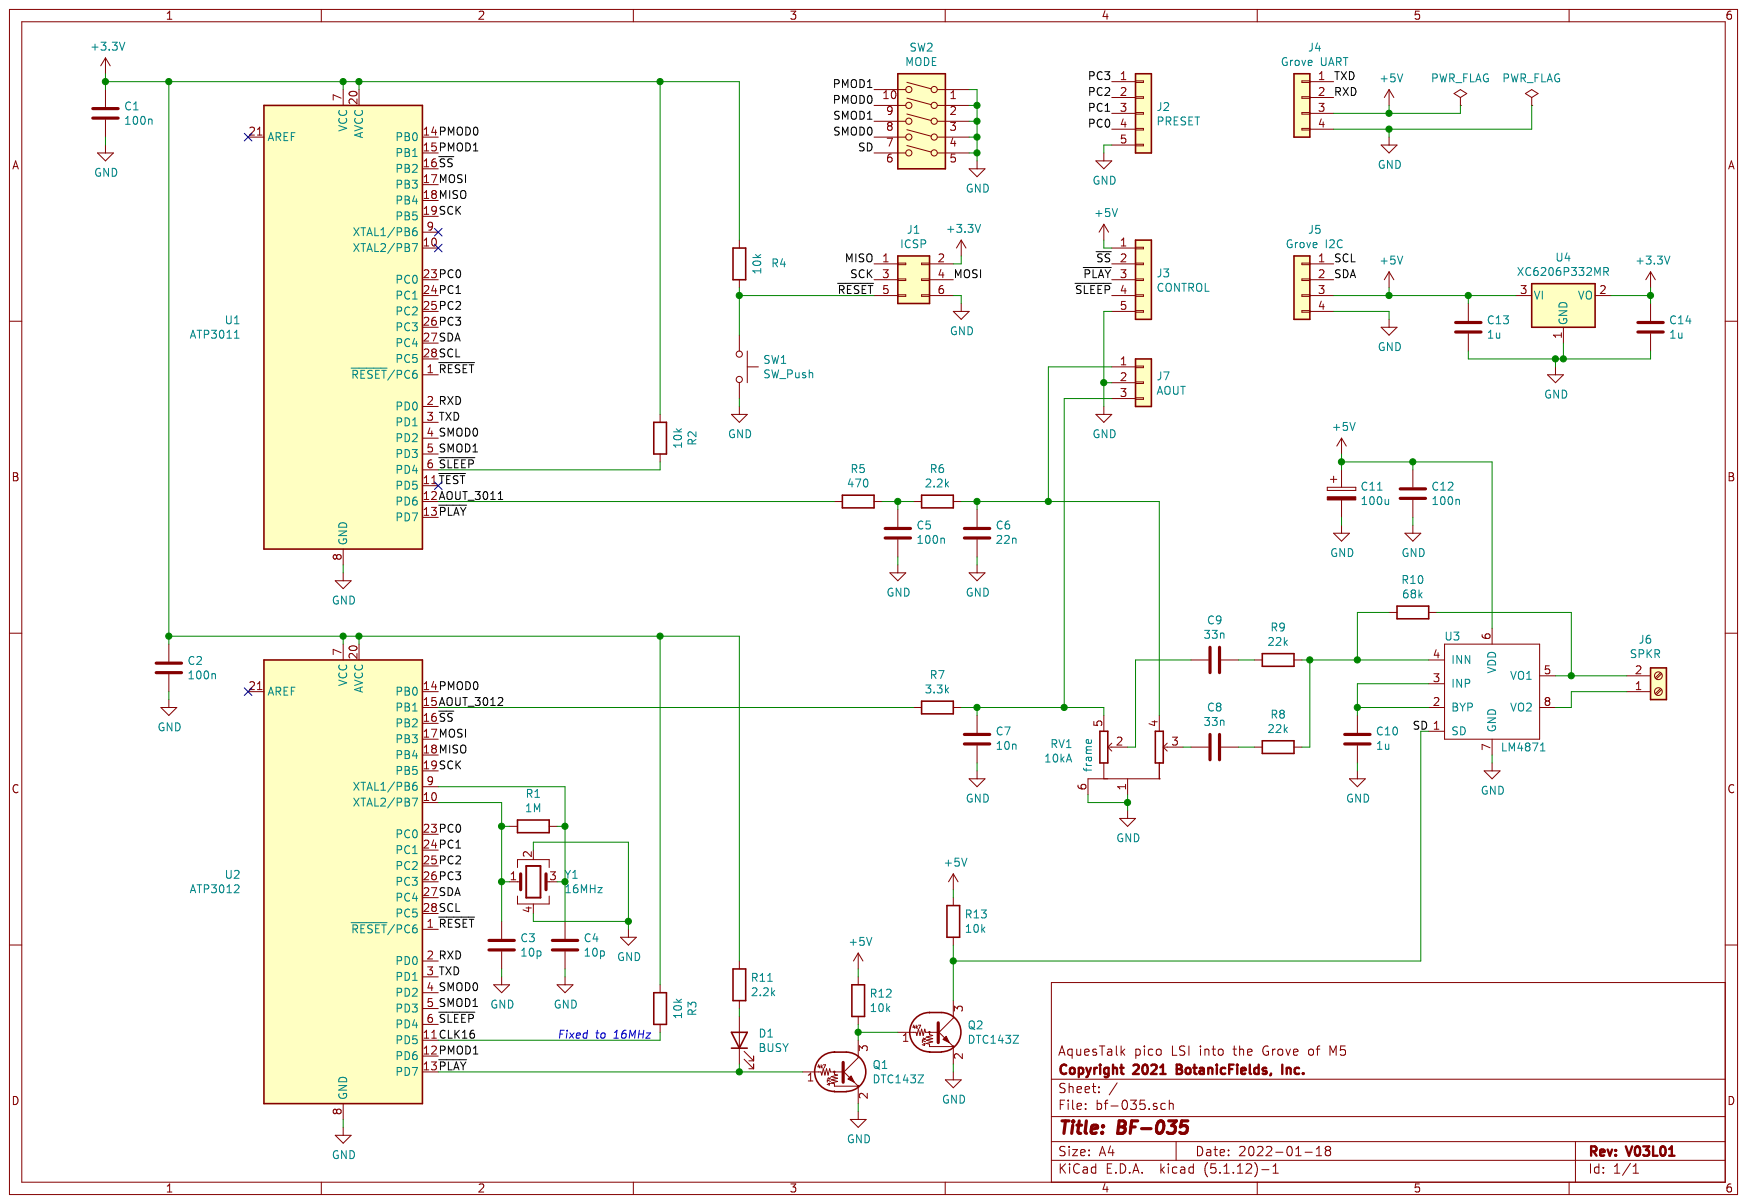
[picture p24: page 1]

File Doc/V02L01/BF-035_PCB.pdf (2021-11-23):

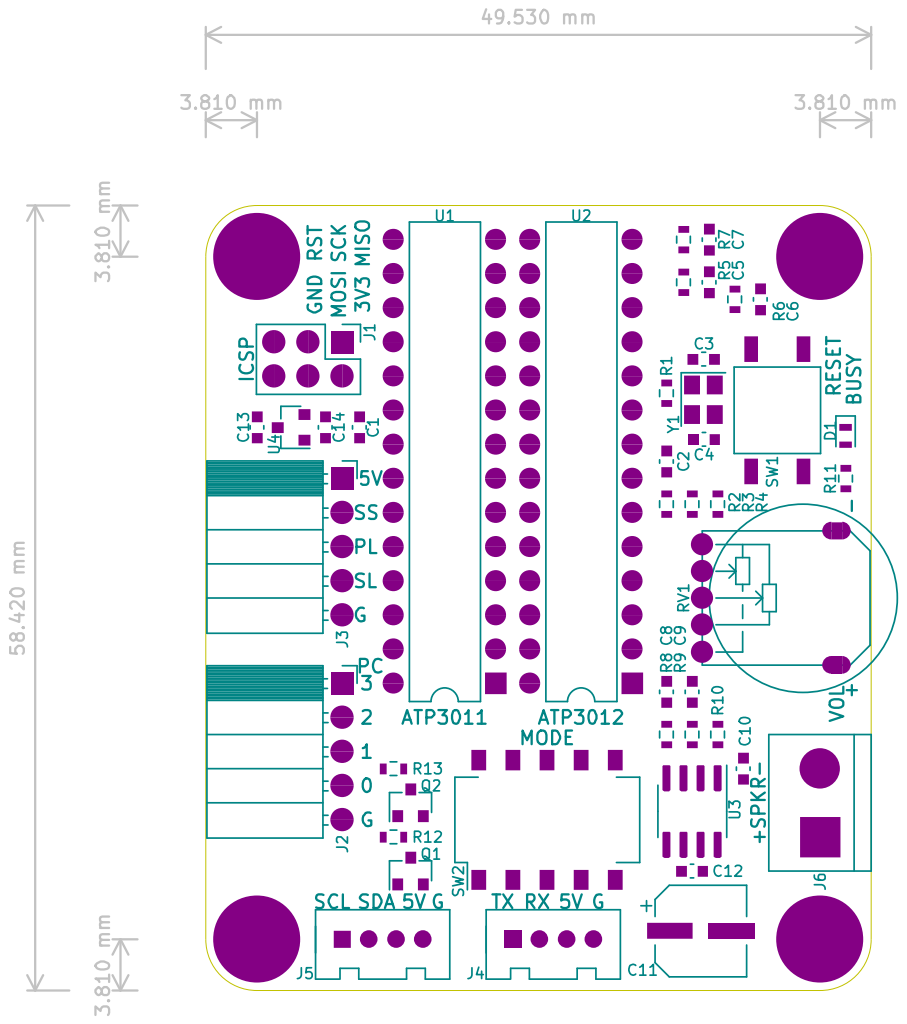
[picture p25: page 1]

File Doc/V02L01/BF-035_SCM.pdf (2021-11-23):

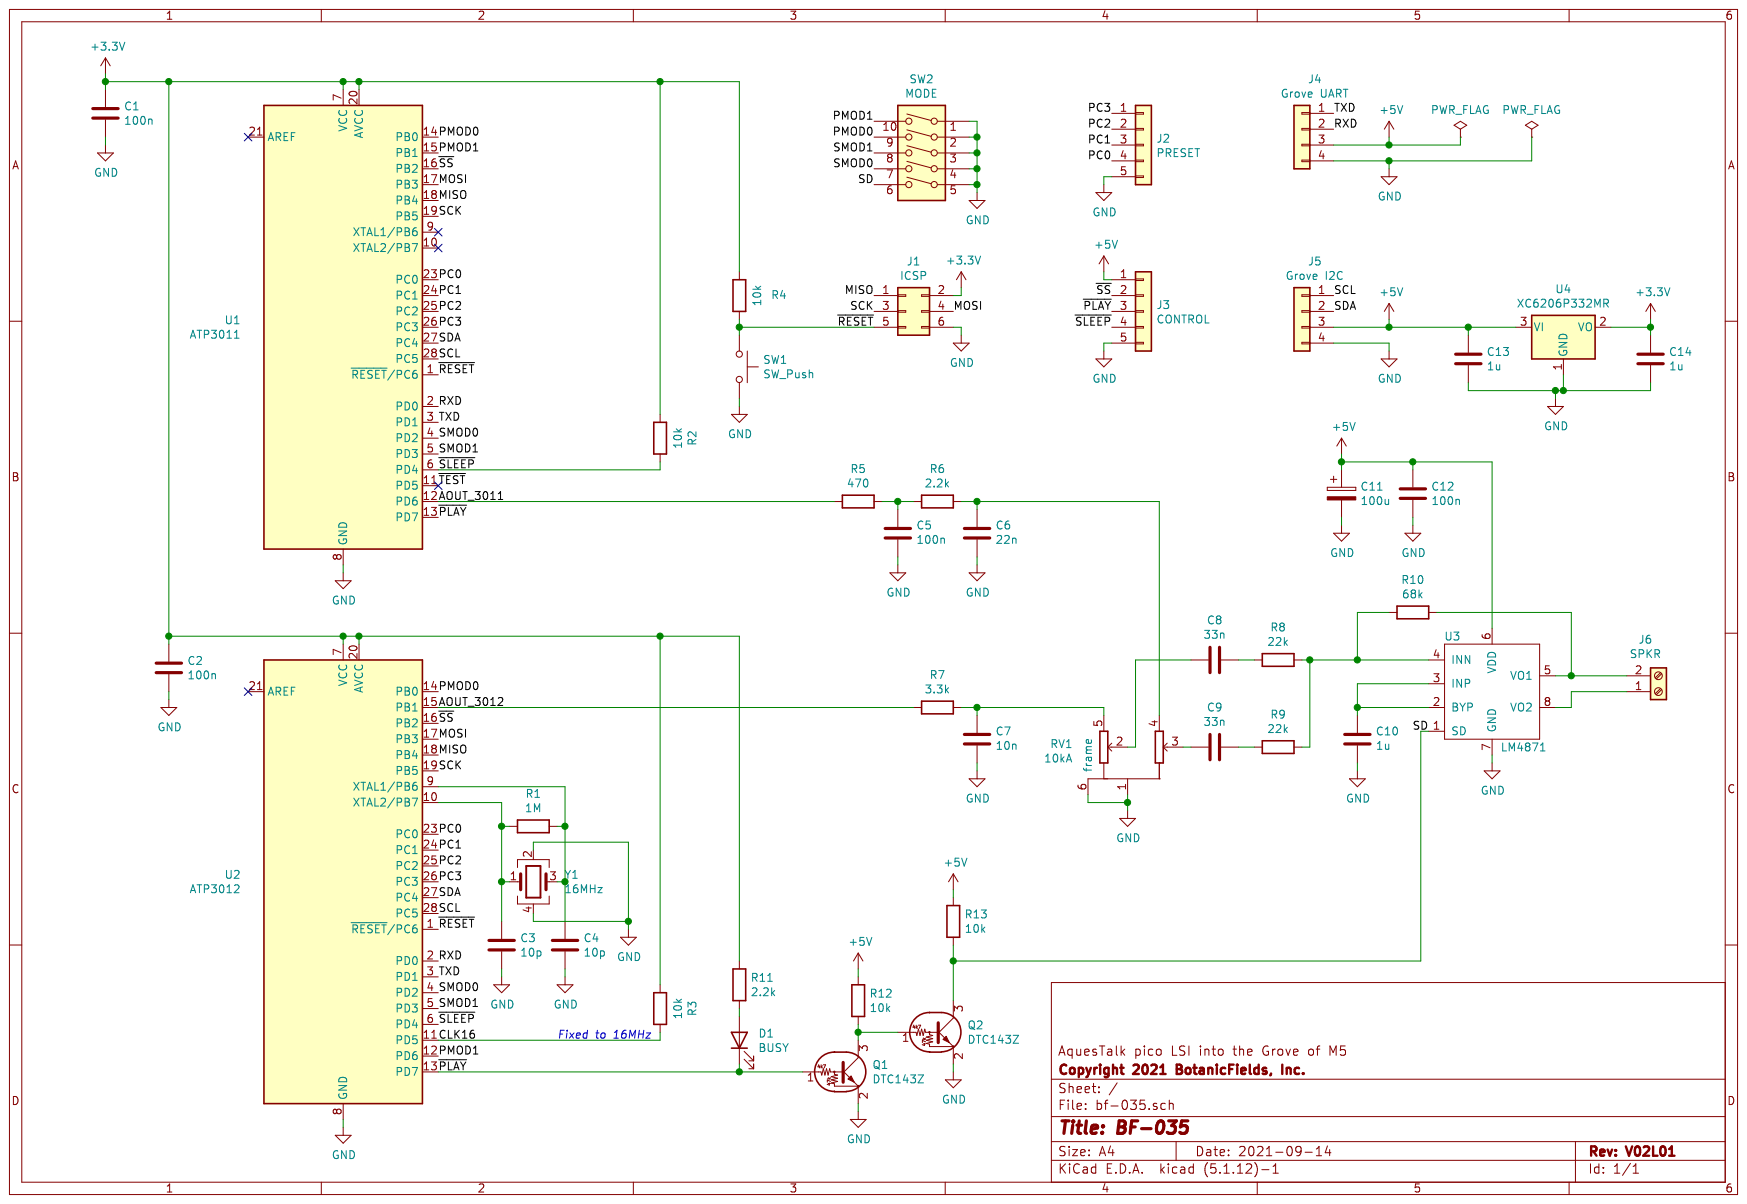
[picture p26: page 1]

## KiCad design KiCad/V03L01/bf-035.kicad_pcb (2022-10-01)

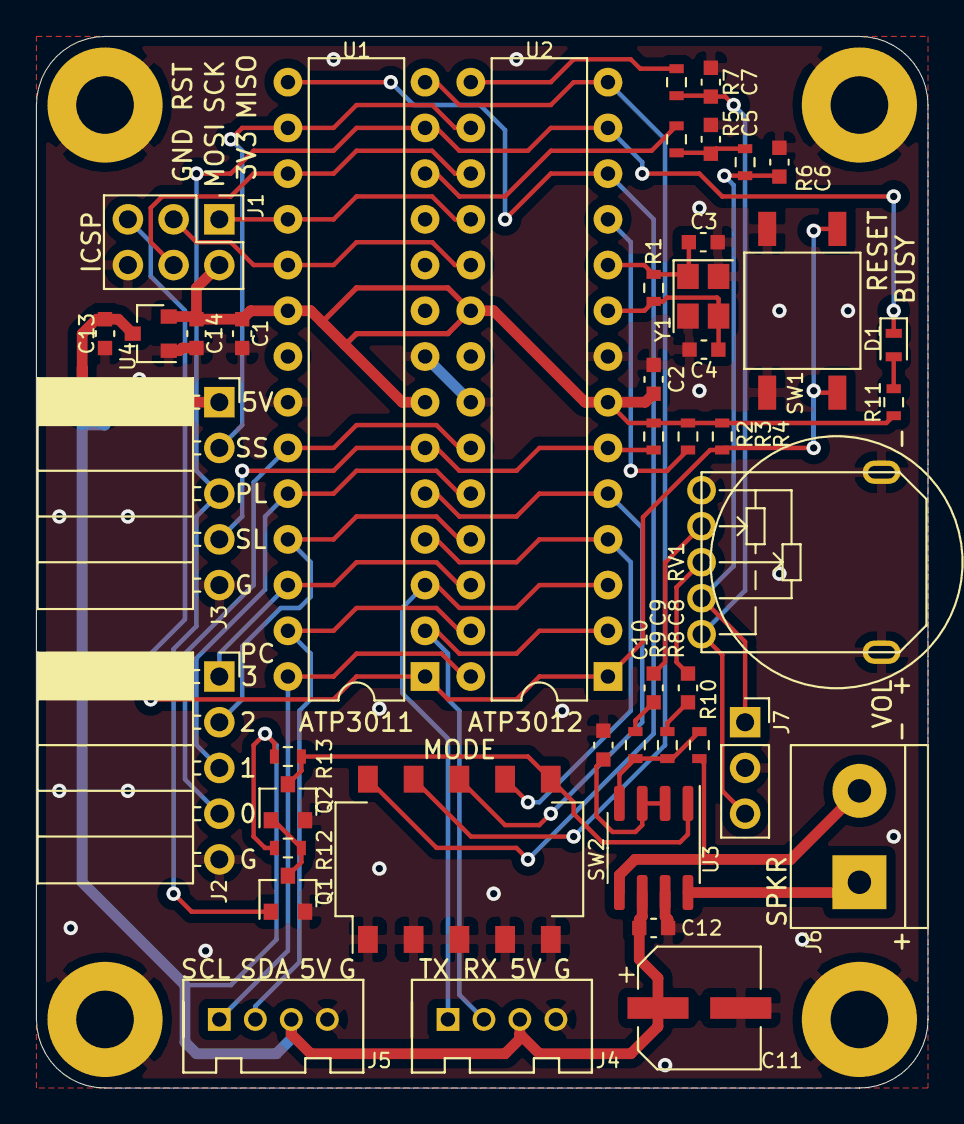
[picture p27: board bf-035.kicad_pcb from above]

Board: 2 copper layers, 49.5 x 58.4 mm, 45 parts (0 on the bottom side), 41 nets.

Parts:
C1, C2, C5, C12: 100n; BF@C_0603_1608Metric
C3, C4: 10p; BF@C_0603_1608Metric
C6: 22n; BF@C_0603_1608Metric
C7: 10n; BF@C_0603_1608Metric
C8, C9: 33n; BF@C_0603_1608Metric
C10, C13, C14: 1u; BF@C_0603_1608Metric
C11: 100u; BF@CP_Elec_6.3x5.3
D1: BUSY; BF@LED_0603_1608Metric
J1: ICSP; PinHeader_2x03_P2.54mm_Vertical
J2: PRESET; PinSocket_1x05_P2.54mm_Horizontal
J3: CONTROL; PinSocket_1x05_P2.54mm_Horizontal
J4: Grove UART; HW4-2.0
J5: Grove I2C; HW4-2.0
J6: SPKR; BF@TerminalBlock_2_P5.08mm_d1.3mm
J7: AOUT; PinSocket_1x03_P2.54mm_Vertical
Q1, Q2: DTC143Z; SOT-23
R1: 1M; BF@R_0603_1608Metric
R2, R3, R4, R12, R13: 10k; BF@R_0603_1608Metric
R5: 470; BF@R_0603_1608Metric
R6, R11: 2.2k; BF@R_0603_1608Metric
R7: 3.3k; BF@R_0603_1608Metric
R8, R9: 22k; BF@R_0603_1608Metric
R10: 68k; BF@R_0603_1608Metric
RV1: 10kA; BF@RK10J
SW1: SW_Push; BF@K2-6639SP
SW2: MODE; SW_DIP_SPSTx05_Slide_Omron_A6S-510x_W8.9mm_P2.54mm
U1: ATP3011; DIP-28_W7.62mm
U2: ATP3012; DIP-28_W7.62mm
U3: LM4871; SOIC-8_3.9x4.9mm_P1.27mm
U4: XC6206P332MR; SOT-23
Y1: 16MHz; Crystal_SMD_3225-4Pin_3.2x2.5mm

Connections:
+3V3: C1.1, C2.1, C14.1, J1.2, R2.2, R3.2, R4.2, R11.1, U1.7, U1.20, U2.7, U2.20, U4.2
+5V: C11.1, C12.1, C13.1, J3.1, J4.3, J5.3, R12.1, R13.1, U3.6, U4.3
/AOUT_3011: R5.2, U1.12
/AOUT_3012: R7.2, U2.15
/CLK16: R3.1, U2.11
/MISO: J1.1, U1.18, U2.18
/MOSI: J1.4, U1.17, U2.17
/PC0: J2.4, U1.23, U2.23
/PC1: J2.3, U1.24, U2.24
/PC2: J2.2, U1.25, U2.25
/PC3: J2.1, U1.26, U2.26
/PMOD0: SW2.9, U1.14, U2.14
/PMOD1: SW2.10, U1.15, U2.12
/RXD: J4.2, U1.2, U2.2
/SCK: J1.3, U1.19, U2.19
/SCL: J5.1, U1.28, U2.28
/SD: Q2.3, R13.2, SW2.6, U3.1
/SDA: J5.2, U1.27, U2.27
/SMOD0: SW2.7, U1.4, U2.4
/SMOD1: SW2.8, U1.5, U2.5
/TXD: J4.1, U1.3, U2.3
/~PLAY: D1.1, J3.3, Q1.1, U1.13, U2.13
/~RESET: J1.5, R4.1, SW1.1, U1.1, U2.1
/~SLEEP: J3.4, R2.1, U1.6, U2.6
/~SS: J3.2, U1.16, U2.16
GND: C1.2, C2.2, C3.2, C4.2, C5.1, C6.1, C7.1, C10.1, C11.2, C12.2, C13.2, C14.2, J1.6, J2.5, J3.5, J4.4, J5.4, J7.2, Q1.2, Q2.2, RV1.1, RV1.6, SW1.2, SW2.1, SW2.2, SW2.3, SW2.4, SW2.5, U1.8, U1.22, U2.8, U2.22, U3.7, U4.1, Y1.2, Y1.4
unnamed: C3.1, R1.2, U2.10, Y1.1
unnamed: C4.1, R1.1, U2.9, Y1.3
unnamed: C5.2, R5.1, R6.2
unnamed: C6.2, J7.1, R6.1, RV1.4
unnamed: C7.2, J7.3, R7.1, RV1.5
unnamed: C8.1, R8.2
unnamed: C8.2, RV1.3
unnamed: C9.1, R9.2
unnamed: C9.2, RV1.2
unnamed: C10.2, U3.2, U3.3
unnamed: D1.2, R11.2
unnamed: J6.1, U3.8
unnamed: J6.2, R10.1, U3.5
unnamed: Q1.3, Q2.1, R12.2
unnamed: R8.1, R9.1, R10.2, U3.4

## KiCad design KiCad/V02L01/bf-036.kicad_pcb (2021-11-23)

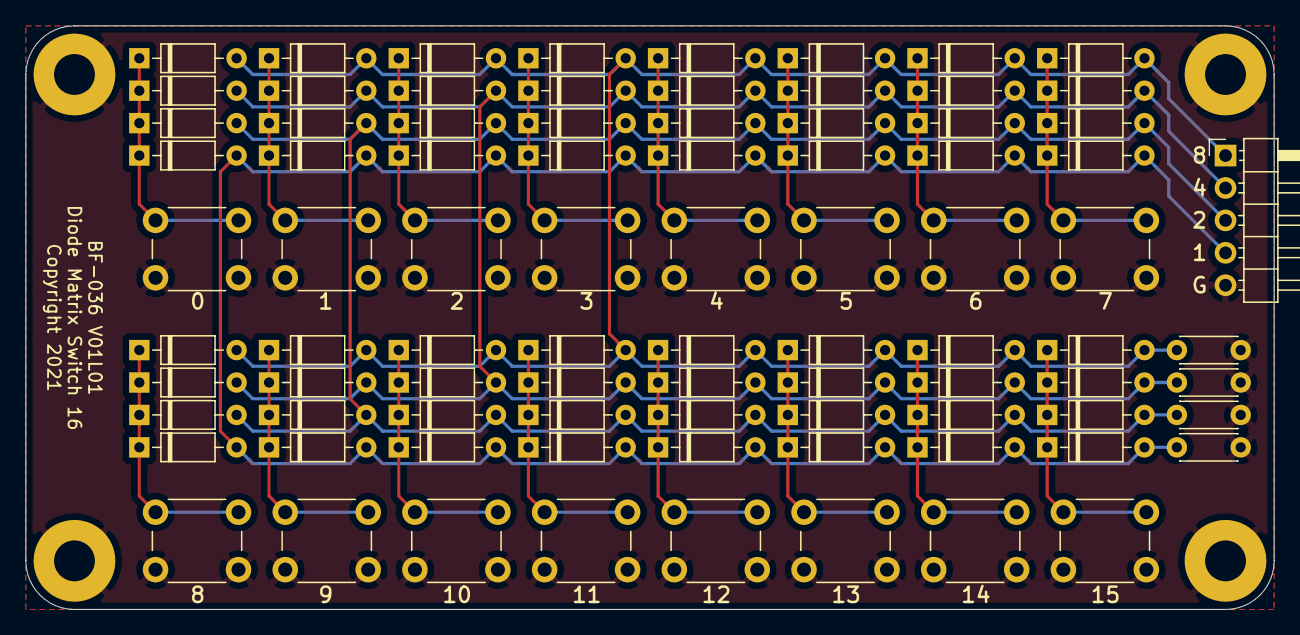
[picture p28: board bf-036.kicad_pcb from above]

Board: 2 copper layers, 97.8 x 45.7 mm, 85 parts (0 on the bottom side), 21 nets.

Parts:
C1, C2, C3, C4: 10n; C_Disc_D4.3mm_W1.9mm_P5.00mm
D1, D2, D3, D4, D5, D6, D7, D8, D9, D10, D11, D12, D13, D14, D15, D16, D17, D18, D19, D20, D21, D22, D23, D24, D25, D26, D27, D28, D29, D30, D31, D32, D33, D34, D35, D36, D37, D38, D39, D40, D41, D42, D43, D44, D45, D46, D47, D48, D49, D50, D51, D52, D53, D54, D55, D56, D57, D58, D59, D60, D61, D62, D63, D64: D; D_DO-35_SOD27_P7.62mm_Horizontal
J1: CODE; PinHeader_1x05_P2.54mm_Horizontal
SW1: 0; SW_PUSH_6mm
SW2: 1; SW_PUSH_6mm
SW3: 2; SW_PUSH_6mm
SW4: 3; SW_PUSH_6mm
SW5: 4; SW_PUSH_6mm
SW6: 5; SW_PUSH_6mm
SW7: 6; SW_PUSH_6mm
SW8: 7; SW_PUSH_6mm
SW9: 8; SW_PUSH_6mm
SW10: 9; SW_PUSH_6mm
SW11: 10; SW_PUSH_6mm
SW12: 11; SW_PUSH_6mm
SW13: 12; SW_PUSH_6mm
SW14: 13; SW_PUSH_6mm
SW15: 14; SW_PUSH_6mm
SW16: 15; SW_PUSH_6mm

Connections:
GND: C1.2, C2.2, C3.2, C4.2, J1.5, SW1.2, SW2.2, SW3.2, SW4.2, SW5.2, SW6.2, SW7.2, SW8.2, SW9.2, SW10.2, SW11.2, SW12.2, SW13.2, SW14.2, SW15.2, SW16.2
unnamed: C1.1, D1.2, D5.2, D9.2, D13.2, D17.2, D21.2, D25.2, D29.2, D33.2, D37.2, D41.2, D45.2, D49.2, D53.2, D57.2, D61.2, J1.1
unnamed: C2.1, D2.2, D6.2, D10.2, D14.2, D18.2, D22.2, D26.2, D30.2, D34.2, D38.2, D42.2, D46.2, D50.2, D54.2, D58.2, D62.2, J1.2
unnamed: C3.1, D3.2, D7.2, D11.2, D15.2, D19.2, D23.2, D27.2, D31.2, D35.2, D39.2, D43.2, D47.2, D51.2, D55.2, D59.2, D63.2, J1.3
unnamed: C4.1, D4.2, D8.2, D12.2, D16.2, D20.2, D24.2, D28.2, D32.2, D36.2, D40.2, D44.2, D48.2, D52.2, D56.2, D60.2, D64.2, J1.4
unnamed: D1.1, D2.1, D3.1, D4.1, SW1.1
unnamed: D5.1, D6.1, D7.1, D8.1, SW2.1
unnamed: D9.1, D10.1, D11.1, D12.1, SW3.1
unnamed: D13.1, D14.1, D15.1, D16.1, SW4.1
unnamed: D17.1, D18.1, D19.1, D20.1, SW5.1
unnamed: D21.1, D22.1, D23.1, D24.1, SW6.1
unnamed: D25.1, D26.1, D27.1, D28.1, SW7.1
unnamed: D29.1, D30.1, D31.1, D32.1, SW8.1
unnamed: D33.1, D34.1, D35.1, D36.1, SW9.1
unnamed: D37.1, D38.1, D39.1, D40.1, SW10.1
unnamed: D41.1, D42.1, D43.1, D44.1, SW11.1
unnamed: D45.1, D46.1, D47.1, D48.1, SW12.1
unnamed: D49.1, D50.1, D51.1, D52.1, SW13.1
unnamed: D53.1, D54.1, D55.1, D56.1, SW14.1
unnamed: D57.1, D58.1, D59.1, D60.1, SW15.1
unnamed: D61.1, D62.1, D63.1, D64.1, SW16.1

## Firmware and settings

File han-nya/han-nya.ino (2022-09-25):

// Copyright 2021 BotanicFields, Inc.
// BF-035 AquesTalk pico LSI into the Grove of M5
// example

// select one from M5STACK, M5ATOM
#define M5STACK
//#define M5ATOM

#ifdef M5STACK
  #include <M5Stack.h>
#endif

#ifdef M5ATOM
  #include <M5Atom.h>
#endif

#include "BF_AquesTalkPicoWire.h"
AquesTalkPicoWire aqtp;

// Han-nya Shingyo
const char* preset_msg[] = {
// message must be less than 127 characters
// ....:....1....:....2....:....3....:....4....:....5....:....6....:....7....:....8....:....9....:....A....:....8....:....C....:..
  "maka-/hannya-haramita-/si'n-gyo-.\r",
  "kanji-zaibo-sa-gyo-jin/hannya-ha-ra-mi-ta-ji-/sho-kengo-onkaiku-do-/issaiku-yaku\r",
  "sha-ri-si-/sikifu-i-ku-/ku-fu-i-siki/sikisokuze-ku-/ku-sokuze-siki/jyu-so-gyo-shikiyaku/bu-nyo-ze-\r",
  "sha-ri-si-ze-/sho-ho-ku-so-/fu-sho-fu-metu/fu-ku-fu-jyo-/fu-zo-fu-gen\r",
  "ze-ko-ku-chu-/mu-siki/mu-jyu-so-gyo-shiki/mu-genni-bi-zessinni-/mu-sikisho-ko-mi-sokuho-/mu-genkainaisi-/mu-i-sikikai\r",
  "mu-mu-myo-yaku/mu-mu-myo-jinnaisi-/mu-ro-si-yaku/mu-ro-si-jin/mu-ku-shu-metudo-/mu-ti-yaku/mu-toku\r",
  "i-mu-sho-tokuko-/bo-daisatta-e-/hannya-ha-ra-mi-ta-ko-\r",
  "sinmu-ke-ge-/mu-ke-ge-ko-/mu-u-ku-fu-/onri-issai/tendo-mu-so-/ku-gyo-ne-han/sanze-sho-butue-/hannya-ha-ra-mi-ta-ko-\r",
  "tokua-nokuta-ra-/sanmyakusanbo-daiko-ti-/hannya-ha-ra-mi-ta-\r",
  "ze-daijinshu-/ze-daimyo-shu-/ze-mu-jyo-shu-/ze-mu-to-do-shu-/no-jo-issaiku-/sinjitufu-ko-\r",
  "ko-setuhannya-ha-ra-mi-ta-shu-/sokusesshu-wa'tu\r",
  "gya-te-/gya-te-/ha-ra-gya-te-/haraso-gya-te-/bo-ji-sowaka-/hannya-sin-gyo-.\r",
};

//..:....1....:....2....:....3....:....4....:....5....:....6....:....7..
// main
enum play_command_t {
  play_stop,
  play_current,
  play_next,
  play_previous,
  play_continuous,  // play continuously from current
  play_forward,     // play continuously from next
  play_backward,    // play continuously from previous
};
play_command_t play_command(play_stop);
int msg_selected(0);

const unsigned int loop_period_ms(100);
      unsigned int loop_last_ms;

void setup()
{
#ifdef M5STACK
  const bool lcd_enable(true);
  const bool sd_enable(true);
  const bool serial_enable(true);
  const bool i2c_enable(true);  // SCL = GPIO22, SDA = GPIO21, frequency = 100kHz
  M5.begin(!lcd_enable, sd_enable, serial_enable, i2c_enable);
  aqtp.Begin(Wire);             // default or safe mode
#endif

#ifdef M5ATOM
  const bool serial_enable(true);
  const bool i2c_enable(true);  // SCL = GPIO21, SDA = GPIO25, frequency = 100kHz
  const bool display_enable(true);
  M5.begin(serial_enable, i2c_enable, !display_enable);

  const int      wire1_sda(26);       // GPIO26
  const int      wire1_scl(32);       // GPIO32
  const uint32_t wire1_freq(100000);  // 100kHz
  Wire1.begin(wire1_sda, wire1_scl, wire1_freq);

  // select Wire(system i2c) or Wire1(Grove connector)
  //aqtp.Begin(Wire);
  aqtp.Begin(Wire1);
#endif

  // "true" if sleep pin is connected
  if (/*true*/ false) {
    const int aqtp_sleep_pin(5);  // GPIO5  for sleep pin of Grove board
    pinMode(aqtp_sleep_pin, OUTPUT);
    digitalWrite(aqtp_sleep_pin, HIGH);
  }

  // "true" to write i2c address into EEPROM
  if (/*true*/ false)
    aqtp.WriteI2cAddress(0x2E);  // change i2c address to customize

  // "true" to write preset message into EEPROM
  if (/*true*/ false)
    aqtp.WritePresetMsg(preset_msg, sizeof(preset_msg)/sizeof(preset_msg[0]));

  // "true" to dump EEPROM to the serial monitor
  if (/*true*/ false)
    aqtp.DumpEeprom();

  aqtp.Send("#V\r");  // read version
  for (int i = 0; i < 10; ++i) {
    aqtp.ShowRes();
    delay(200);
  }
  aqtp.Send("#J\r");  // chime sound J
  for (int i = 0; i < 10; ++i) {
    aqtp.ShowRes();
    delay(200);
  }
  aqtp.Send("#K\r");  // chime sound K
  for (int i = 0; i < 10; ++i) {
    aqtp.ShowRes();
    delay(200);
  }

  // for Han-nya Shingyo
  aqtp.WriteSpeed(70);
  aqtp.WritePause();

  // play control
  play_command = play_stop;
  msg_selected = 0;

  // loop control
  loop_last_ms = millis();
}

void loop()
{
  // buttons
  M5.update();

#ifdef M5STACK
  if (M5.BtnA.wasReleased()) {
    if (aqtp.Busy()) {
      aqtp.Send("$");  // Abort
    }
    play_command = play_previous;
  }
  if (M5.BtnB.wasReleased()) {
    if (aqtp.Busy()) {
      aqtp.Send("$");  // Abort
      play_command = play_stop;
    }
    else {
      msg_selected = 0;
      play_command = play_continuous;
    }
  }
  if (M5.BtnC.wasReleased()) {
    if (aqtp.Busy()) {
      aqtp.Send("$");  // Abort
    }
    play_command = play_forward;
  }
#endif

#ifdef M5ATOM
  if (M5.Btn.wasReleased()) {
    if (aqtp.Busy()) {
      aqtp.Send("$");  // Abort
      play_command = play_stop;
    }
    else {
      msg_selected = 0;
      play_command = play_continuous;
    }
  }
#endif

  // play messages
  int num_of_msg = sizeof(preset_msg)/sizeof(preset_msg[0]);

  switch (play_command) {
    case play_current:
      if (!aqtp.Busy()) {
        aqtp.Send(preset_msg[msg_selected]);
        play_command = play_stop;
      }
      break;
    case play_next:
      if (!aqtp.Busy()) {
        if (++msg_selected >= num_of_msg)
          msg_selected = 0;
        aqtp.Send(preset_msg[msg_selected]);
        play_command = play_stop;
      }
      break;
    case play_previous:
      if (!aqtp.Busy()) {
        if (--msg_selected < 0)
          msg_selected = num_of_msg - 1;
        aqtp.Send(preset_msg[msg_selected]);
        play_command = play_stop;
      }
      break;
    case play_continuous:
      if (!aqtp.Busy()) {
        delay(500);
        aqtp.Send(preset_msg[msg_selected]);
        if (++msg_selected >= num_of_msg)
          msg_selected = 0;
      }
      break;
    case play_forward:
      if (!aqtp.Busy()) {
        if (++msg_selected >= num_of_msg)
          msg_selected = 0;
        delay(500);
        aqtp.Send(preset_msg[msg_selected]);
      }
      break;
    case play_backward:
      if (!aqtp.Busy()) {
        if (--msg_selected < 0)
          msg_selected = num_of_msg - 1;
        delay(500);
        aqtp.Send(preset_msg[msg_selected]);
      }
      break;
    default:
      play_command = play_stop;
      break;
  }
  aqtp.ShowRes(2);

  // loop control
  unsigned int delay_ms(0);
  unsigned int elapse_ms = millis() - loop_last_ms;
  if (elapse_ms < loop_period_ms) {
    delay_ms = loop_period_ms - elapse_ms;
  }
  delay(delay_ms);
  loop_last_ms = millis();
//  Serial.printf("loop elapse = %dms\n", elapse_ms);  // for monitoring elapsed time
}

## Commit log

2021-12-18 examples
    add unsigned related to millis()
2022-08-22 Busy() added
    Busy() added and button operations are improved
2022-10-01 PCB V03
    add PCB V03
    [bf-035.kicad_pcb, bf-035.sch, bf-035v3_bom.csv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]
